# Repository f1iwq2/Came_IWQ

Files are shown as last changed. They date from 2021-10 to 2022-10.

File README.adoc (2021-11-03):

Carte CAME-IWQ
==============

Carte de remplacement pour portail coulissants CAME
ZBX6N/7N - A base d'arduino nano
Documents dans le fichier pdf
Fichiers schéma Kicad
fichiers gerber dans le répertoire trace

Replacement control board for CAME sliding gates
Documents in pdf files
Kicad board schematics files
gerber files in trace directory

https://youtu.be/OYu1DCdmt-g

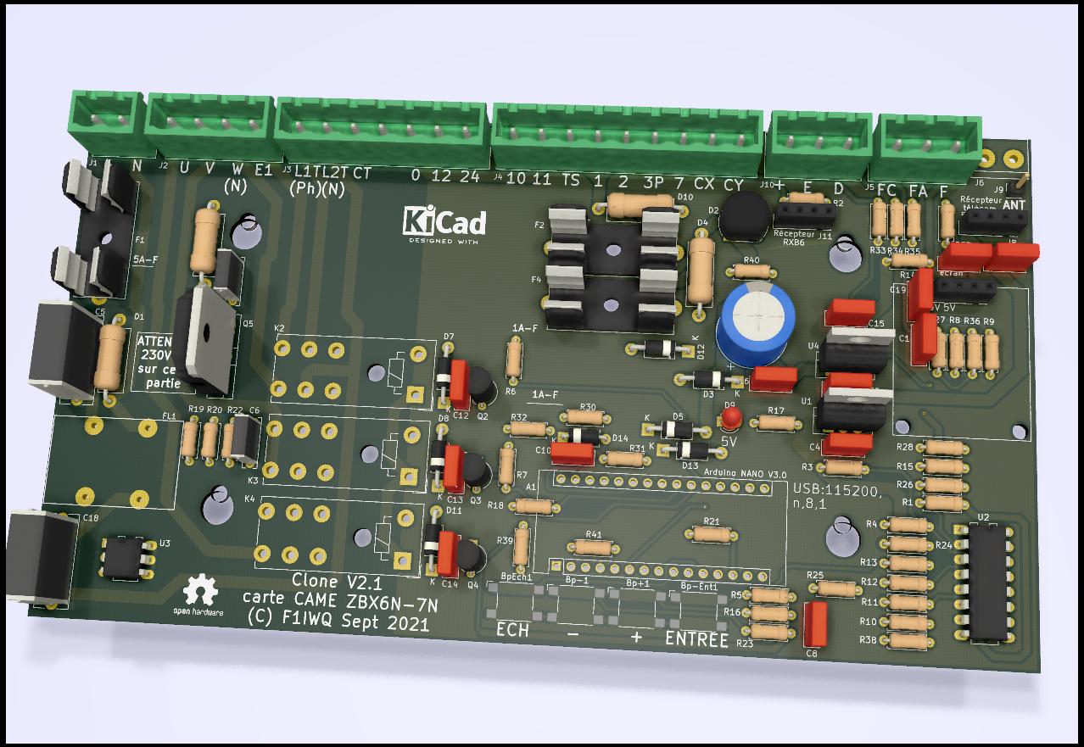
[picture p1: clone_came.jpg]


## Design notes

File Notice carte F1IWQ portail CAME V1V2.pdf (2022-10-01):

## Notice carte F1IWQ clone CAME V1.0/2.0

## En remplacement de la carte ZBX6N/7N

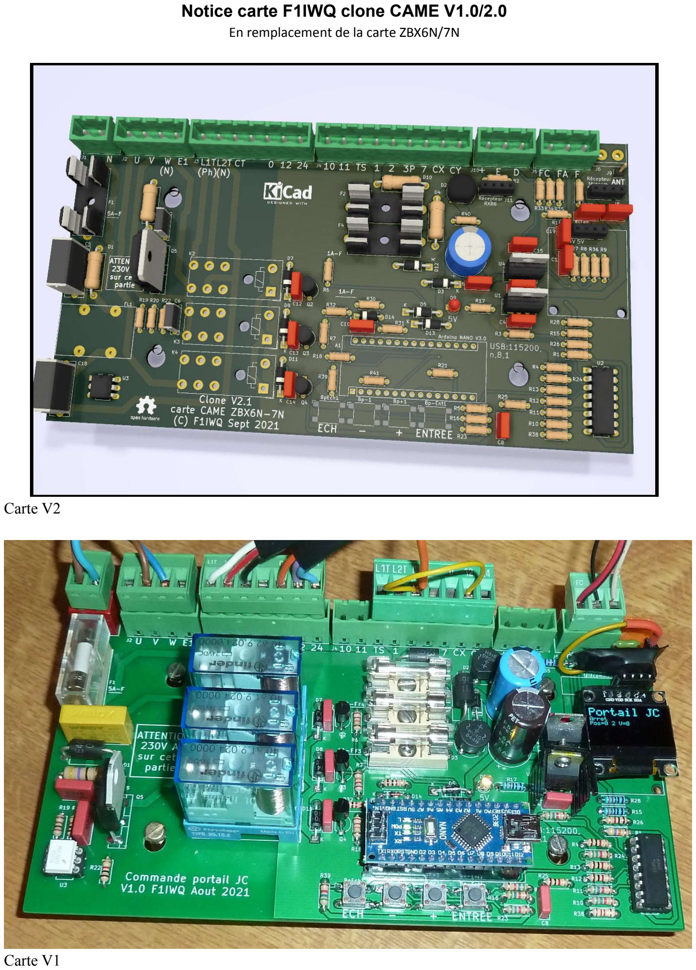
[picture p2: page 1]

## Carte V2

## Carte V1

# Description

## La carte existe en deux versions :

La carte V1.0 dispose d'un connecteur pour un récepteur radio à 1 bornier.
La carte V2.1 dispose de deux connecteurs pour un récepteur à 1 ou 2 bornier(s) (type RXB6).

La carte comporte des protections contre les surtensions par des diodes transil, beaucoup plus réactives que les traditionnelles varistances. En cas de surtension, le fusible associé à la diode brule.

# Montage

Pour la carte V1, souder un strap entre H11 et H12.
Monter les supports de relais avec une vis + écrou M3, de même que les supports des fusibles. Ne pas trop serrer les écrous des supports de relais sous peine de déformation.
Ponter JP1 ou JP2 à la soudure suivant le récepteur de télécommande utilisé (carte V1.0) pour les récepteurs signalés plus bas, souder JP2.
Insérer l'écran OLED sur le connecteur J7 et mettre deux vis / écrous M2,5 avec entretoise.
Insérer le récepteur de télécommande.
Insérer les fusibles rapides 5x20 sur leurs supports. Leur valeur est sérigraphiée. F1=5A-F, F2 F3 F4=1A-F. Insérer l'arduino NANO programmé à l'emplacement A1, prise USB vers la droite.
Monter la carte dans le boitier CAME et insérer les borniers. Il est impératif de respecter la phase (L) et le neutre (N) sur le bornier J1.

L'origine de la mesure par l'encodeur est fixée sur le fin de course arrière (portail ouvert). Tant que cette position n'a pas été reconnue (c’est-à-dire que le fdc arrière doit avoir été actionné par le portail au moins une fois), le portail se déplacera en petite vitesse (PV).

# Télécommande

Le récepteur utilise la librairie rc-switch, compatible uniquement avec les télécommandes à code fixe équipées

## des puces suivantes :

## SC5262 / SC5272 Séries 2262: HX2262 / LX2262 / PT2262 Séries 2272: HX2272 / PT2272 / Séries 1527: EV1527 / RT1527 / FP1527 / HS1527 Intertechno outlets HT6P20X

La télécommande TOP 432 EV CAME fonctionne quelque fois. Les télécommandes Somfy, Cardin ne fonctionnent pas.

Rc-switch permet de décoder 12 protocoles. Le tableau ci-dessous donne le nom du protocole en fonction du numéro du protocole affiché.

1 | EV1527
2
3
4
5
6 | HTP20B
7 | HS2303-PT (utilisé dans la télécommande AUKEY)
8 | Conrad RS-200 RX
9 | Conrad RS-200 TX
10 | 1ByOne Doorbell
11 | HT12E
12 | SM5212

# Circuit imprimé V1.0 avec référencement des composants

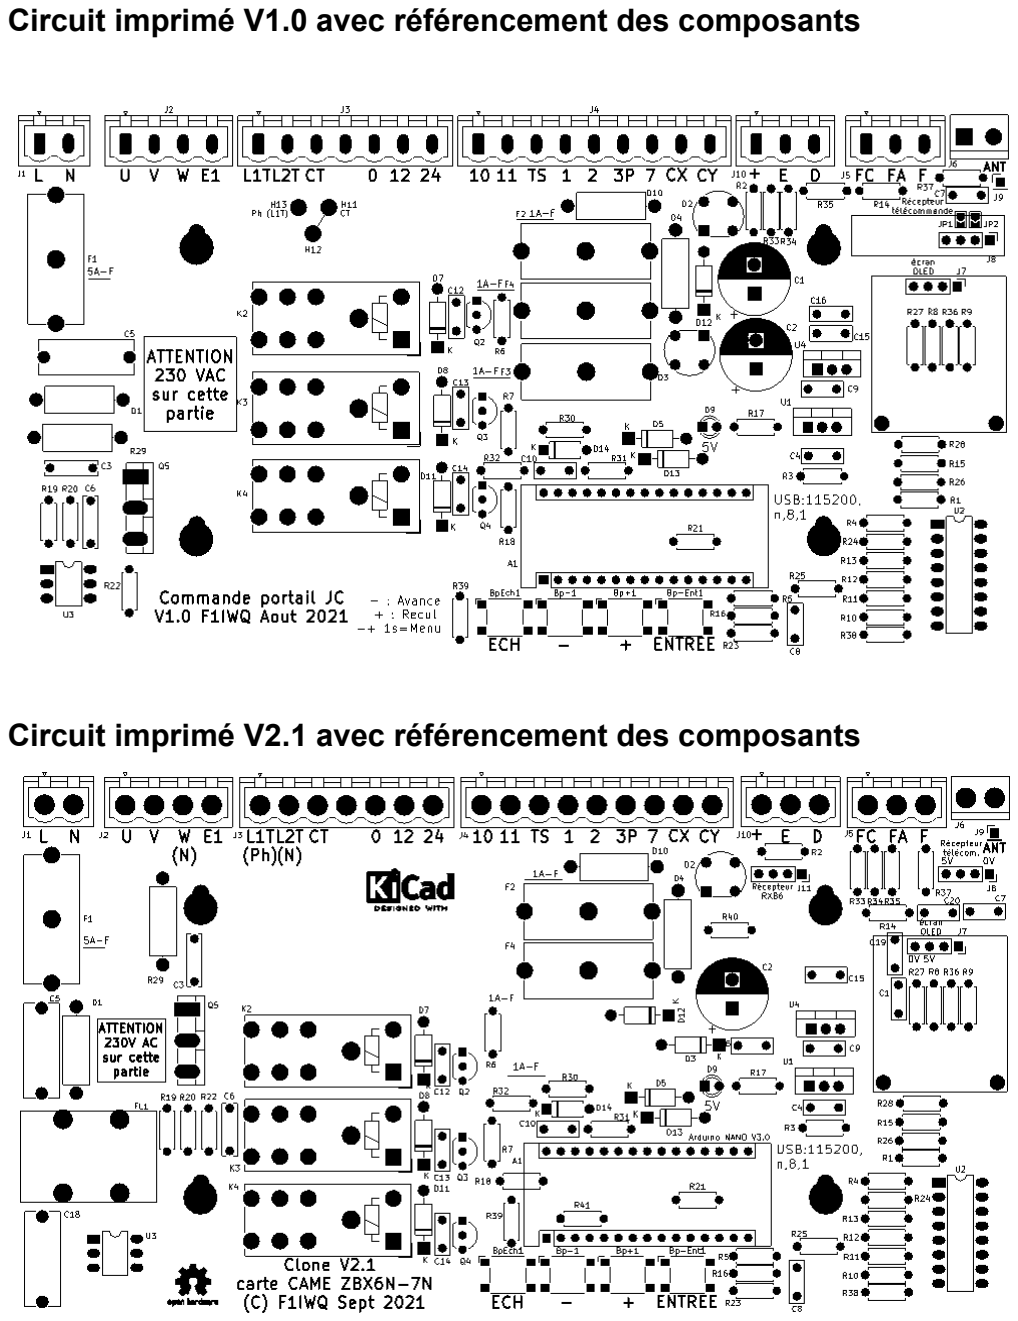
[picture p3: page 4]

# Circuit imprimé V2.1 avec référencement des composants

# Nomenclature V1.0

A1 | Arduino_Nano_v3.x | Module:Arduino_Nano
Bp+1 | SW_MEC_5E | Button_Switch_SMD:SW_SPST_Omron_B3FS-101xP
Bp-1 | SW_MEC_5E | Button_Switch_SMD:SW_SPST_Omron_B3FS-101xP
BpEch1 | SW_MEC_5E | Button_Switch_SMD:SW_SPST_Omron_B3FS-101xP
Bp-Ent1 | SW_MEC_5E | Button_Switch_SMD:SW_SPST_Omron_B3FS-101xP
C1 | 470µF | Capacitor_THT:CP_Radial_D12.5mm_P5.00mm
C10 | 1nF | Capacitor_THT:C_Rect_L7.2mm_W2.5mm_P5.00mm_FKS2_FKP2_MKS2_MKP2
C12 | 100 nF | Capacitor_THT:C_Rect_L7.2mm_W2.5mm_P5.00mm_FKS2_FKP2_MKS2_MKP2
C13 | 100 nF | Capacitor_THT:C_Rect_L7.2mm_W2.5mm_P5.00mm_FKS2_FKP2_MKS2_MKP2
C14 | 100 nF | Capacitor_THT:C_Rect_L7.2mm_W2.5mm_P5.00mm_FKS2_FKP2_MKS2_MKP2
C15 | 100nF | Capacitor_THT:C_Rect_L7.2mm_W2.5mm_P5.00mm_FKS2_FKP2_MKS2_MKP2
C16 | 100nF | Capacitor_THT:C_Rect_L7.2mm_W2.5mm_P5.00mm_FKS2_FKP2_MKS2_MKP2
C2 | 470µF | Capacitor_THT:CP_Radial_D12.5mm_P5.00mm
C3 | 10nF 400V | Capacitor_THT:C_Rect_L9.0mm_W2.5mm_P7.50mm_MKT
C4 | 100nF | Capacitor_THT:C_Rect_L7.2mm_W2.5mm_P5.00mm_FKS2_FKP2_MKS2_MKP2
C5 | 100nF | Capacitor_THT:C_Rect_L16.5mm_W6.0mm_P15.00mm_MKT
C6 | 10nF 400V | Capacitor_THT:C_Rect_L9.0mm_W2.5mm_P7.50mm_MKT
C7 | 100nF | Capacitor_THT:C_Rect_L7.2mm_W2.5mm_P5.00mm_FKS2_FKP2_MKS2_MKP2
C8 | 100nF | Capacitor_THT:C_Rect_L7.2mm_W2.5mm_P5.00mm_FKS2_FKP2_MKS2_MKP2
C9 | 100nF | Capacitor_THT:C_Rect_L7.2mm_W2.5mm_P5.00mm_FKS2_FKP2_MKS2_MKP2
D1 | 1.5KE300CA | Diode_THT:R_Axial_DIN0414_L11.9mm_D4.5mm_P15.24mm_Horizontal
D10 | 1.5KE30CA | Diode_THT:R_Axial_DIN0414_L11.9mm_D4.5mm_P15.24mm_Horizontal
D11 | 1N4004 | Diode_THT:D_DO-41_SOD81_P10.16mm_Horizontal
D12 | 1N4004 | Diode_THT:D_DO-41_SOD81_P10.16mm_Horizontal
D13 | 1N4004 | Diode_THT:D_DO-41_SOD81_P10.16mm_Horizontal
D14 | 5.1V | Diode_THT:D_A-405_P7.62mm_Horizontal
D2 | W04G | Diode_THT:Diode_Bridge_Round_D8.9mm
D3 | W04G | Diode_THT:Diode_Bridge_Round_D8.9mm
D4 | 1.5KE30CA | Diode_THT:R_Axial_DIN0414_L11.9mm_D4.5mm_P15.24mm_Horizontal
D5 | 1N4004 | Diode_THT:D_DO-41_SOD81_P10.16mm_Horizontal
D7 | 1N4004 | Diode_THT:D_DO-41_SOD81_P10.16mm_Horizontal
D8 | 1N4004 | Diode_THT:D_DO-41_SOD81_P10.16mm_Horizontal
D9 | LED | LED_THT:LED_D3.0mm
F1 | Fuse | Fuse:Fuseholder_Cylinder-5x20mm_Schurter_0031_8201_Horizontal_Open + capot
F2 | Fuse | Fuse:Fuseholder_Cylinder-5x20mm_Schurter_0031_8201_Horizontal_Open
F3 | Fuse | Fuse:Fuseholder_Cylinder-5x20mm_Schurter_0031_8201_Horizontal_Open
F4 | Fuse | Fuse:Fuseholder_Cylinder-5x20mm_Schurter_0031_8201_Horizontal_Open
J1 | Conn_01x02_Male | Connector_Phoenix_MSTB:PhoenixContact_MSTBVA_2,5_2-G-5,08_1x02_P5.08mm_Vertical
J10 | Conn_01x03_Male | Connector_Phoenix_MSTB:PhoenixContact_MSTBVA_2,5_3-G-5,08_1x03_P5.08mm_Vertical
J2 | Conn_01x04_Male | Connector_Phoenix_MSTB:PhoenixContact_MSTBVA_2,5_4-G_1x04_P5.08mm_Vertical
J3 | Conn_01x07_Male | Connector_Phoenix_MSTB:PhoenixContact_MSTBVA_2,5_7-G_1x07_P5.08mm_Vertical
J4 | Conn_01x09_Male | Connector_Phoenix_MSTB:PhoenixContact_MSTBVA_2,5_9-G_1x09_P5.08mm_Vertical
J5 | Conn_01x03_Male | Connector_Phoenix_MSTB:PhoenixContact_MSTBVA_2,5_3-G-5,08_1x03_P5.08mm_Vertical
J6 | Screw_Terminal_01x02 | TerminalBlock:TerminalBlock_bornier-2_P5.08mm
J7 | Conn_01x04 | Connector_PinHeader_2.54mm:PinHeader_1x04_P2.54mm_Vertical
J8 | Conn_01x04 | Connector_PinHeader_2.54mm:PinHeader_1x04_P2.54mm_Vertical
J9 | Conn_01x04 | Connector_PinHeader_2.54mm:PinHeader_1x01_P2.54mm_Vertical
JP1 | SolderJumper_2_Open | Jumper:SolderJumper-2_P1.3mm_Open_TrianglePad1.0x1.5mm
JP2 | SolderJumper_2_Open | Jumper:SolderJumper-2_P1.3mm_Open_TrianglePad1.0x1.5mm
K2 | Finder 40.62.9.024V | Relay_THT:Relay_socket_95.15.2
K3 | Finder 40.61.9.024V | Relay_THT:Relay_socket_95.15.2
K4 | Finder 40.61.9.024V | Relay_THT:Relay_socket_95.15.2
Q2 | BS170 | Package_TO_SOT_THT:TO-92L_Inline_Wide
Q3 | BS170 | Package_TO_SOT_THT:TO-92L_Inline_Wide
Q4 | BS170 | Package_TO_SOT_THT:TO-92L_Inline_Wide
Q5 | BTA26-600-BWRG ou BTA26-800-BWRG | Package_TO_SOT_THT:TO-3P-3_Vertical
R1 | 47k | Resistor_THT:R_Axial_DIN0207_L6.3mm_D2.5mm_P7.62mm_Horizontal
R10 | 5,6k | Resistor_THT:R_Axial_DIN0207_L6.3mm_D2.5mm_P7.62mm_Horizontal
R11 | 5,6k | Resistor_THT:R_Axial_DIN0207_L6.3mm_D2.5mm_P7.62mm_Horizontal
R12 | 1k | Resistor_THT:R_Axial_DIN0207_L6.3mm_D2.5mm_P7.62mm_Horizontal
R13 | 1k | Resistor_THT:R_Axial_DIN0207_L6.3mm_D2.5mm_P7.62mm_Horizontal
R14 | 2,7k | Resistor_THT:R_Axial_DIN0207_L6.3mm_D2.5mm_P7.62mm_Horizontal
R15 | 330 | Resistor_THT:R_Axial_DIN0207_L6.3mm_D2.5mm_P7.62mm_Horizontal
R16 | 5,6k | Resistor_THT:R_Axial_DIN0207_L6.3mm_D2.5mm_P7.62mm_Horizontal
R17 | 330 | Resistor_THT:R_Axial_DIN0207_L6.3mm_D2.5mm_P7.62mm_Horizontal
R18 | 12k | Resistor_THT:R_Axial_DIN0207_L6.3mm_D2.5mm_P7.62mm_Horizontal
R19 | 100 | Resistor_THT:R_Axial_DIN0207_L6.3mm_D2.5mm_P7.62mm_Horizontal
R2 | 1,8k | Resistor_THT:R_Axial_DIN0207_L6.3mm_D2.5mm_P7.62mm_Horizontal
R20 | 1k | Resistor_THT:R_Axial_DIN0207_L6.3mm_D2.5mm_P7.62mm_Horizontal
R21 | 330 | Resistor_THT:R_Axial_DIN0207_L6.3mm_D2.5mm_P7.62mm_Horizontal
R22 | 1k | Resistor_THT:R_Axial_DIN0207_L6.3mm_D2.5mm_P7.62mm_Horizontal
R23 | 5,6k | Resistor_THT:R_Axial_DIN0207_L6.3mm_D2.5mm_P7.62mm_Horizontal
R24 | 5,6k | Resistor_THT:R_Axial_DIN0207_L6.3mm_D2.5mm_P7.62mm_Horizontal
R25 | 1k | Resistor_THT:R_Axial_DIN0207_L6.3mm_D2.5mm_P7.62mm_Horizontal
R26 | 1k | Resistor_THT:R_Axial_DIN0207_L6.3mm_D2.5mm_P7.62mm_Horizontal

R27 | 1,8k | Resistor_THT:R_Axial_DIN0207_L6.3mm_D2.5mm_P7.62mm_Horizontal
R28 | 330 | Resistor_THT:R_Axial_DIN0207_L6.3mm_D2.5mm_P7.62mm_Horizontal
R29 | 47 2W | Resistor_THT:R_Axial_DIN0414_L11.9mm_D4.5mm_P15.24mm_Horizontal
R3 | 5,6k | Resistor_THT:R_Axial_DIN0207_L6.3mm_D2.5mm_P7.62mm_Horizontal
R30 | 1k | Resistor_THT:R_Axial_DIN0207_L6.3mm_D2.5mm_P7.62mm_Horizontal
R31 | 5,6k | Resistor_THT:R_Axial_DIN0207_L6.3mm_D2.5mm_P7.62mm_Horizontal
R32 | 1k | Resistor_THT:R_Axial_DIN0207_L6.3mm_D2.5mm_P7.62mm_Horizontal
R33 | 150 | Resistor_THT:R_Axial_DIN0207_L6.3mm_D2.5mm_P7.62mm_Horizontal
R34 | 1k | Resistor_THT:R_Axial_DIN0207_L6.3mm_D2.5mm_P7.62mm_Horizontal
R35 | 10k | Resistor_THT:R_Axial_DIN0207_L6.3mm_D2.5mm_P7.62mm_Horizontal
R36 | 47k | Resistor_THT:R_Axial_DIN0207_L6.3mm_D2.5mm_P7.62mm_Horizontal
R37 | 0 | Resistor_THT:R_Axial_DIN0207_L6.3mm_D2.5mm_P7.62mm_Horizontal
R38 | 1,2k | Resistor_THT:R_Axial_DIN0207_L6.3mm_D2.5mm_P7.62mm_Horizontal
R39 | 5,6k | Resistor_THT:R_Axial_DIN0207_L6.3mm_D2.5mm_P7.62mm_Horizontal
R4 | 1k | Resistor_THT:R_Axial_DIN0207_L6.3mm_D2.5mm_P7.62mm_Horizontal
R5 | 5,6k | Resistor_THT:R_Axial_DIN0207_L6.3mm_D2.5mm_P7.62mm_Horizontal
R6 | 12k | Resistor_THT:R_Axial_DIN0207_L6.3mm_D2.5mm_P7.62mm_Horizontal
R7 | 12k | Resistor_THT:R_Axial_DIN0207_L6.3mm_D2.5mm_P7.62mm_Horizontal
R8 | 2,7k | Resistor_THT:R_Axial_DIN0207_L6.3mm_D2.5mm_P7.62mm_Horizontal
R9 | 2,7k | Resistor_THT:R_Axial_DIN0207_L6.3mm_D2.5mm_P7.62mm_Horizontal
U1 | 7805+radiateur | Package_TO_SOT_THT:TO-220-3_Vertical
U2 | ACPL-844 ou 4xSFH620 | Package_DIP:DIP-16_W7.62mm_LongPads
U3 | MOC3020M | Package_DIP:DIP-6_W7.62mm_LongPads
U4 | 7824+radiateur | Package_TO_SOT_THT:TO-220-3_Vertical

# Nomenclature V2.0

A1 | Arduino_Nano_v3.x | Module:Arduino_Nano
Bp+1 | SW_MEC_5E | Button_Switch_SMD:SW_SPST_Omron_B3FS-101xP
Bp-1 | SW_MEC_5E | Button_Switch_SMD:SW_SPST_Omron_B3FS-101xP
BpEch1 | SW_MEC_5E | Button_Switch_SMD:SW_SPST_Omron_B3FS-101xP
Bp-Ent1 | SW_MEC_5E | Button_Switch_SMD:SW_SPST_Omron_B3FS-101xP
C1 | 100nF | Capacitor_THT:C_Rect_L7.2mm_W2.5mm_P5.00mm_FKS2_FKP2_MKS2_MKP2
C10 | 1nF | Capacitor_THT:C_Rect_L7.2mm_W2.5mm_P5.00mm_FKS2_FKP2_MKS2_MKP2
C12 | 100 nF | Capacitor_THT:C_Rect_L7.2mm_W2.5mm_P5.00mm_FKS2_FKP2_MKS2_MKP2
C13 | 100 nF | Capacitor_THT:C_Rect_L7.2mm_W2.5mm_P5.00mm_FKS2_FKP2_MKS2_MKP2
C14 | 100 nF | Capacitor_THT:C_Rect_L7.2mm_W2.5mm_P5.00mm_FKS2_FKP2_MKS2_MKP2
C15 | 100nF | Capacitor_THT:C_Rect_L7.2mm_W2.5mm_P5.00mm_FKS2_FKP2_MKS2_MKP2
C16 | 100nF | Capacitor_THT:C_Rect_L7.2mm_W2.5mm_P5.00mm_FKS2_FKP2_MKS2_MKP2
C18 | 100nF 400V | Capacitor_THT:C_Rect_L16.5mm_W6.0mm_P15.00mm_MKT
C19 | 100nF | Capacitor_THT:C_Rect_L7.2mm_W2.5mm_P5.00mm_FKS2_FKP2_MKS2_MKP2
C2 | 1000µF 35V | Capacitor_THT:CP_Radial_D12.5mm_P5.00mm
C20 | 100nF | Capacitor_THT:C_Rect_L7.2mm_W2.5mm_P5.00mm_FKS2_FKP2_MKS2_MKP2
C3 | 10nF 400V | Capacitor_THT:C_Rect_L9.0mm_W2.5mm_P7.50mm_MKT
C4 | 100nF | Capacitor_THT:C_Rect_L7.2mm_W2.5mm_P5.00mm_FKS2_FKP2_MKS2_MKP2
C5 | 100nF 400V | Capacitor_THT:C_Rect_L16.5mm_W6.0mm_P15.00mm_MKT
C6 | 10nF 400V | Capacitor_THT:C_Rect_L9.0mm_W2.5mm_P7.50mm_MKT
C7 | 100nF | Capacitor_THT:C_Rect_L7.2mm_W2.5mm_P5.00mm_FKS2_FKP2_MKS2_MKP2
C8 | 100nF | Capacitor_THT:C_Rect_L7.2mm_W2.5mm_P5.00mm_FKS2_FKP2_MKS2_MKP2
C9 | 100nF | Capacitor_THT:C_Rect_L7.2mm_W2.5mm_P5.00mm_FKS2_FKP2_MKS2_MKP2
D1 | 1.5KE400CA | Diode_THT:R_Axial_DIN0414_L11.9mm_D4.5mm_P15.24mm_Horizontal
D10 | 1.5KE39CA | Diode_THT:R_Axial_DIN0414_L11.9mm_D4.5mm_P15.24mm_Horizontal
D11 | 1N4004 | Diode_THT:D_DO-41_SOD81_P10.16mm_Horizontal
D12 | 1N4004 | Diode_THT:D_DO-41_SOD81_P10.16mm_Horizontal
D13 | 1N4004 | Diode_THT:D_DO-41_SOD81_P10.16mm_Horizontal
D14 | DZ5.1V | Diode_THT:D_A-405_P7.62mm_Horizontal
D2 | W04G | Diode_THT:Diode_Bridge_Round_D8.9mm
D3 | 1N4004 | Diode_THT:D_DO-41_SOD81_P10.16mm_Horizontal
D4 | 1.5KE39CA | Diode_THT:R_Axial_DIN0414_L11.9mm_D4.5mm_P15.24mm_Horizontal
D5 | 1N4004 | Diode_THT:D_DO-41_SOD81_P10.16mm_Horizontal
D7 | 1N4004 | Diode_THT:D_DO-41_SOD81_P10.16mm_Horizontal
D8 | 1N4004 | Diode_THT:D_DO-41_SOD81_P10.16mm_Horizontal
D9 | LED | LED_THT:LED_D3.0mm
F1 | Fuse | Fuse:Fuseholder_Cylinder-5x20mm_Schurter_0031_8201_Horizontal_Open + capot
F2 | Fuse | Fuse:Fuseholder_Cylinder-5x20mm_Schurter_0031_8201_Horizontal_Open
F4 | Fuse | Fuse:Fuseholder_Cylinder-5x20mm_Schurter_0031_8201_Horizontal_Open
FL1 | Wurth 7446223001 | Filter:Filtre_wurth
J1 | Conn_01x02_Male | Connector_Phoenix_MSTB:PhoenixContact_MSTBVA_2,5_2-G-5,08_1x02_P5.08mm_Vertical
J10 | Conn_01x03_Male | Connector_Phoenix_MSTB:PhoenixContact_MSTBVA_2,5_3-G-5,08_1x03_P5.08mm_Vertical
J11 | Conn_01x04 | Connector_PinSocket_2.54mm:PinSocket_1x04_P2.54mm_Vertical
J2 | Conn_01x04_Male | Connector_Phoenix_MSTB:PhoenixContact_MSTBVA_2,5_4-G-5,08_1x04_P5.08mm_Vertical
J3 | Conn_01x07_Male | Connector_Phoenix_MSTB:PhoenixContact_MSTBVA_2,5_7-G-5,08_1x07_P5.08mm_Vertical
J4 | Conn_01x09_Male | Connector_Phoenix_MSTB:PhoenixContact_MSTBVA_2,5_9-G-5,08_1x09_P5.08mm_Vertical
J5 | Conn_01x03_Male | Connector_Phoenix_MSTB:PhoenixContact_MSTBVA_2,5_3-G-5,08_1x03_P5.08mm_Vertical
J6 | Screw_Terminal_01x02 | TerminalBlock:TerminalBlock_bornier-2_P5.08mm
J7 | Conn_01x04 | Connector_PinSocket_2.54mm:PinSocket_1x04_P2.54mm_Vertical
J8 | Conn_01x04 | Connector_PinSocket_2.54mm:PinSocket_1x04_P2.54mm_Vertical
J9 | Conn_01x04 | Connector_PinHeader_2.54mm:PinHeader_1x01_P2.54mm_Vertical
K2 | Finder 40.62.9.024V | Relay_THT:Relay_socket_95.15.2
K3 | Finder 40.61.9.024V | Relay_THT:Relay_socket_95.15.2
K4 | Finder 40.61.9.024V | Relay_THT:Relay_socket_95.15.2
Q2 | BS170 | Package_TO_SOT_THT:TO-92L_Inline_Wide
Q3 | BS170 | Package_TO_SOT_THT:TO-92L_Inline_Wide
Q4 | BS170 | Package_TO_SOT_THT:TO-92L_Inline_Wide
Q5 | BTA26-600-BWRG | Package_TO_SOT_THT:TO-3P-3_Vertical
R1 | 47k | Resistor_THT:R_Axial_DIN0207_L6.3mm_D2.5mm_P7.62mm_Horizontal
R10 | 5,6k | Resistor_THT:R_Axial_DIN0207_L6.3mm_D2.5mm_P7.62mm_Horizontal
R11 | 5,6k | Resistor_THT:R_Axial_DIN0207_L6.3mm_D2.5mm_P7.62mm_Horizontal
R12 | 1k | Resistor_THT:R_Axial_DIN0207_L6.3mm_D2.5mm_P7.62mm_Horizontal
R13 | 1k | Resistor_THT:R_Axial_DIN0207_L6.3mm_D2.5mm_P7.62mm_Horizontal
R14 | 2,7k | Resistor_THT:R_Axial_DIN0207_L6.3mm_D2.5mm_P7.62mm_Horizontal
R15 | 330 | Resistor_THT:R_Axial_DIN0207_L6.3mm_D2.5mm_P7.62mm_Horizontal
R16 | 5,6k | Resistor_THT:R_Axial_DIN0207_L6.3mm_D2.5mm_P7.62mm_Horizontal
R17 | 330 | Resistor_THT:R_Axial_DIN0207_L6.3mm_D2.5mm_P7.62mm_Horizontal
R18 | 12k | Resistor_THT:R_Axial_DIN0207_L6.3mm_D2.5mm_P7.62mm_Horizontal
R19 | 100 | Resistor_THT:R_Axial_DIN0207_L6.3mm_D2.5mm_P7.62mm_Horizontal
R2 | 4,7k | Resistor_THT:R_Axial_DIN0207_L6.3mm_D2.5mm_P7.62mm_Horizontal
R20 | 1k | Resistor_THT:R_Axial_DIN0207_L6.3mm_D2.5mm_P7.62mm_Horizontal
R21 | 330 | Resistor_THT:R_Axial_DIN0207_L6.3mm_D2.5mm_P7.62mm_Horizontal
R22 | 1k | Resistor_THT:R_Axial_DIN0207_L6.3mm_D2.5mm_P7.62mm_Horizontal
R23 | 5,6k | Resistor_THT:R_Axial_DIN0207_L6.3mm_D2.5mm_P7.62mm_Horizontal
R24 | 5,6k | Resistor_THT:R_Axial_DIN0207_L6.3mm_D2.5mm_P7.62mm_Horizontal
R25 | 1k | Resistor_THT:R_Axial_DIN0207_L6.3mm_D2.5mm_P7.62mm_Horizontal
R26 | 1k | Resistor_THT:R_Axial_DIN0207_L6.3mm_D2.5mm_P7.62mm_Horizontal

R27 | 4,7k | Resistor_THT:R_Axial_DIN0207_L6.3mm_D2.5mm_P7.62mm_Horizontal
R28 | 330 | Resistor_THT:R_Axial_DIN0207_L6.3mm_D2.5mm_P7.62mm_Horizontal
R29 | 47 2W | Resistor_THT:R_Axial_DIN0414_L11.9mm_D4.5mm_P15.24mm_Horizontal
R3 | 5,6k | Resistor_THT:R_Axial_DIN0207_L6.3mm_D2.5mm_P7.62mm_Horizontal
R30 | 1k | Resistor_THT:R_Axial_DIN0207_L6.3mm_D2.5mm_P7.62mm_Horizontal
R31 | 6,8k | Resistor_THT:R_Axial_DIN0207_L6.3mm_D2.5mm_P7.62mm_Horizontal
R32 | 1k | Resistor_THT:R_Axial_DIN0207_L6.3mm_D2.5mm_P7.62mm_Horizontal
R33 | 150 | Resistor_THT:R_Axial_DIN0207_L6.3mm_D2.5mm_P7.62mm_Horizontal
R34 | 1k | Resistor_THT:R_Axial_DIN0207_L6.3mm_D2.5mm_P7.62mm_Horizontal
R35 | 10k | Resistor_THT:R_Axial_DIN0207_L6.3mm_D2.5mm_P7.62mm_Horizontal
R36 | 47k | Resistor_THT:R_Axial_DIN0207_L6.3mm_D2.5mm_P7.62mm_Horizontal
R37 | 0 | Resistor_THT:R_Axial_DIN0207_L6.3mm_D2.5mm_P7.62mm_Horizontal
R38 | 1,2k | Resistor_THT:R_Axial_DIN0207_L6.3mm_D2.5mm_P7.62mm_Horizontal
R39 | 5,6k | Resistor_THT:R_Axial_DIN0207_L6.3mm_D2.5mm_P7.62mm_Horizontal
R4 | 1k | Resistor_THT:R_Axial_DIN0207_L6.3mm_D2.5mm_P7.62mm_Horizontal
R40 | 220 | Resistor_THT:R_Axial_DIN0207_L6.3mm_D2.5mm_P7.62mm_Horizontal
R41 | 47k | Resistor_THT:R_Axial_DIN0207_L6.3mm_D2.5mm_P7.62mm_Horizontal
R5 | 5,6k | Resistor_THT:R_Axial_DIN0207_L6.3mm_D2.5mm_P7.62mm_Horizontal
R6 | 12k | Resistor_THT:R_Axial_DIN0207_L6.3mm_D2.5mm_P7.62mm_Horizontal
R7 | 12k | Resistor_THT:R_Axial_DIN0207_L6.3mm_D2.5mm_P7.62mm_Horizontal
R8 | 2,7k | Resistor_THT:R_Axial_DIN0207_L6.3mm_D2.5mm_P7.62mm_Horizontal
R9 | 2,7k | Resistor_THT:R_Axial_DIN0207_L6.3mm_D2.5mm_P7.62mm_Horizontal
U1 | 7805+radiateur | Package_TO_SOT_THT:TO-220-3_Vertical
U2 | ACPL-844 ou 4xSFH620 | Package_DIP:DIP-16_W7.62mm_LongPads
U3 | MOC3020M | Package_DIP:DIP-6_W7.62mm_LongPads
U4 | 7824+radiateur | Package_TO_SOT_THT:TO-220-3_Vertical

## Connecteurs phoenix contact:

Ces connecteurs sont composés d'une partie mâle à souder et d'une partie femelle à bornier constituant deux références de commande séparées.
| | | Commande | Commande
Nb | | | Conn mâle | conn femelle
pts | Rep | Type | à souder | à bornier
2 | J1 | MSTBVA 2,5/2-G-5,08 | 17 55 73 6 | 17 57 01 9
3 | J5-J10 MSTBVA 2,5/3-G-5,08 | 17 55 74 9 | 17 57 02 2
4 | J2 | MSTBVA 2,5/4-G-5,08 | 17 55 75 2 | 17 57 03 5
7 | J3 | MSTBVA 2,5/7-G-5,08 | 17 55 78 1 | 17 57 06 4
9 | J4 | MSTBVA 2,5/9-G-5,08 | 17 55 80 4 | 17 57 08 0

Les régulateurs U1 et U4 doivent absolument être montés sur des radiateurs.

R37 est un fusible 1A au format résistance. Ref Little fuse 251001.NRT1L. A monter sur support.

Les relais K2 K3 et K4 sont montés sur support finder référence 95.15.2. Attention K2 est un relais 2RT ; K3 et K4 sont des relais 1RT.

A1 est un arduino NANO, il peut être un clone chinois.

## Le module OLED est un 0,96" 128x64

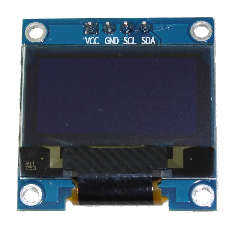
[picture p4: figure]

## Le récepteur radio commande (433,920 MHz) est MX-RM-5V (peu performant)

## ou TDCA RX500A 433,920 MHz (plus sensible)

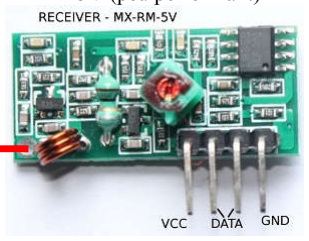
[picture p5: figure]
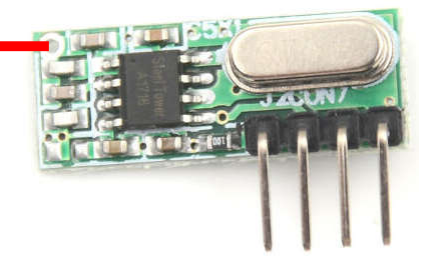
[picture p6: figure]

ou RXB6 (super hétérodyne : plus sensible, plus sélectif) ; nécessite la version 2 de la carte.

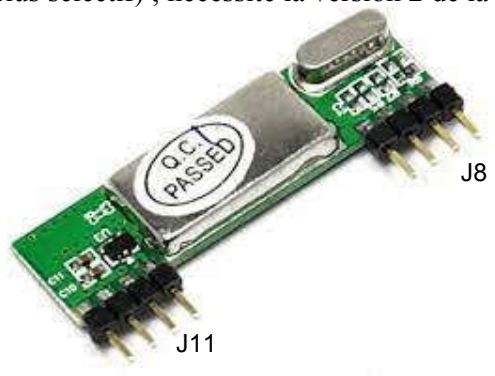
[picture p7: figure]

Le module RXB6 ci-dessus est à enficher sur les connecteurs J8 et J11.

Les modules MX-RM-5V et TDCA RX500A sont à enficher sur le connecteur J8. Pour ces deux récepteurs, il faut souder un fil d'antenne du trait rouge jusqu'au point J9 via un fil.

Il est conseillé d'isoler avec du ruban adhésif électricien l'arrière et le devant des récepteurs.

### antenne

### antenne

# Liste des écrans

## Menu

L'entrée dans le menu pour le paramétrage se fait en appuyant sur le bouton ENTREE pendant 1 seconde.

## Ecran 1

## L'écran menu affiche des paramètres modifiables ou non ainsi que des commandes :

## Apprentissage Sens d'ouverture=x Sequencement=x Sauvegarde EPROM Gestion telecomm Affichage entrees Tps max fonction:xx Tps accel Tps decel

## Ecran 2: gestion des télécommandes

Pour changer de ligne appuyer sur + ou -.

## Pour choisir une ligne appuyer sur ENTREE Pour sortie appuyer sur ECH

## Apprentissage :

Effectue un aller-retour du portail pour fixer l'origine de l'encodeur et les positions de ralentissement avant et arrière dans l'eeprom.
Sens d'ouverture 0 ou 1 : correspond au paramètre F54 0=ouverture à gauche 1=ouverture à droite Sequencement 0 ou 1 : correspond au paramètre F7 0=pas à pas (ouverture fermeture sans arrêt)

## 1=séquentielle (ouverture arret fermeture arret) Sauvegarde EPROM : écrit les paramètres modifiés dans l'EPROM pour la sauvegarde Gestion telecommandes : affiche/ajoute/supprime des télécommandes

### **MENU** >Apprentissage Sens d'ouverture=0 Sequencement=1 Sauvegarde EPROM Gestion telecomm Affichage entrees Tps max fonction:99

1 telecomm.

>Ajouter telecom.
Liste/Suppr telecom.

## Affichage des entrées : affiche les entrées en dynamique (fin de course et boutons)

Tps max fonctionn: Temps maximal de fonctionnement en secondes au-delà duquel le portail s'arrête. Tps accel/decel : Temps de d'accélération et de décélération en dixièmes de secondes.

## Pour ajouter une télécommande

## Sélectionner la ligne Gestion telecommandes Sélectionner "Ajouter telecom" et appuyer sur ENTREE

Appuyer sur le bouton de la télécommande à ajouter.
Si le nombre maximal de télécommandes est atteint, un message d'erreur s'affiche.
Si la télécommande avait déjà été ajoutée, un message s'affiche.
Si rien ne s'affiche quand on appuie sur la télécommande, c'est qu'elle n'est pas reconnue (fréquence ou protocole non reconnus).
Après avoir ajouté une ou plusieurs télécommandes, ne pas oublier d'écrire l'EEPROM pour la sauvegarde.

Liste et suppression des télécommandes : sélectionner "Liste/Suppr des telecom" et appuyer sur ENTREE

Le nombre de télécommandes est affiché (maximum 20).

## La première colonne affiche le numéro de la télécommande

La deuxième colonne affiche le code d'identification de la télécommande (plus précisément d'un de ses

## boutons)

## Pour supprimer une télécommande :

## Sélectionner la télécommande à supprimer Supprimer la télécommande sélectionnée en appuyant 1s sur ENTREE

Après avoir supprimé une ou plusieurs télécommandes, ne pas oublier d'écrire l'EEPROM pour la sauvegarde.

## Mode exploitation

En mode exploitation (hors mode menu) si on appuie sur une télécommande, et que le protocole est reconnu,

## l'écran affiche les informations transmises par la télécommande :

8745 est le code du bouton de la télécommande qui vient d'envoyer le signal.

## 12b signifie que c'est un code de 12 bits

Pr:11 signifie que c'est le protocole 11.

## PORTAIL IWQ

### Pos=5465 15s V=208

### 8745 12b Pr:11 OK

2telecomm.

>1 26898
2 94119

OK que la télécommande est enregistrée en EPROM, et qu'elle est donc reconnue.

La position du portail par l'encodeur est affichée (5465).
Si un mouvement est en cours, le temps en secondes de la durée du mouvement est affiché (ici 15s).

## V=208 indique la vitesse du portail (en points encodeur/0,3s)

Si la durée de mouvement est supérieure au temps maximal de fonctionnement, le mouvement s'arrête sur un message d'erreur.

Si la cellule est occultée (entrée CX sur bornier J4), un message s'affiche et le portail ne pourra pas être manœuvré.

## Un appui sur la touche "+" avance le portail Un appui sur la touche "-" recule le portail Un appui sur la touche "ECH" arrête le portail

En cours d'avancée si un obstacle survient, le portail recule en petite vitesse. En cours de recul, si un obstacle survient, le portail s'arrête.

# Erreurs pouvant être affichées

## - Secteur non trouvé

Indique que la tension secteur n'a pas été trouvée.

## - Erreur mvt trop long

Indique que le temps maximum de fonctionnement a été atteint. Cette erreur arrête le portail.

## - Encodeur muet

L'encodeur n'a pas envoyé de changement de position du moteur alors qu'un mouvement est en cours. Cette erreur arrête le portail si celui-ci est en mouvement de recul, et recule le portail si celui-ci est en mouvement d'avance.

# Consommation du 24VAC

## Consommations relevées sans accessoires branchés sur 10-11 : Au repos : 153 mA En fonctionnement : 263 mA

# Programme Arduino

Le programme est unique pour les deux versions de la carte, il existe une directive de compilation pour la destination du programme en V1 ou V2.

L'entrée analogiques "Onde" est acquise en sous-programme IRQ Timer1. Pour acquérir les valeurs analogiques en temps masqué, le programme manipule directement les registres de l'ATMega328P.

Sur la V1.0 l'encodeur est sur la broche D8, ce qui nécessite de faire réagir l'interruption PCINT0.
Sur la V2.0 l'encodeur est sur la broche D3, ce qui nécessite de faire réagir l'interruption INT1.

Il existe une directive de compilation V1/V2 pour adapter le programme à la version de la carte :

#define V1 // carte V1.0 ou V2.0

Le nombre de boutons de télécommandes maximal est de 20. Il peut être augmenté à concurrence de la saturation mémoire des variables globales.

#define | Nbre_Max_telecom 20 | // nombre maxi de télécommandes

L'interruption timer 1 est générée toutes les 217 µs. Elle gère la génération du signal gâchette du triac U3 vers Q5, pour la modulation de vitesse GV/PV. L'onde secteur est numérisée pour permettre d'avoir le départ du pilotage de la gâchette après changement de signe de l'onde secteur. En GV le triac envoie la totalité de la sinusoïde secteur. En PV, le triac envoie une sinusoïde sur deux (réduction de 50% de la vitesse).

La modulation de vitesse peut être également obtenue de 0 à 100% en faisant varier l'angle de retard à l'amorçage de la gâchette du triac. Dans ce cas on envoie une partie de la sinusoïde à 50 Hz:

La liaison USB dispose d'un terminal de commandes permet de piloter le moteur, de changer des variables etc. Taper ? sur un terminal USB à 115200 bauds pour avoir la liste des commandes disponibles (terminal arduino). Il permet également de piloter le menu grâce aux touches "ENTREE" "8+entrée" pour - et "2+entrée" pour +.

Attention: le programme ne fonctionne pas si l'écran OLED n'est pas alimenté.

### Sinusoïde en sortie du triac en GV (mode1/1)

### Sinusoïde en sortie du triac en PV (mode 1/2)

### Sinusoïde en sortie du triac en décélération de GV à PV (mode 2/3)

## Options internes du programme

## Le programme dispose de deux modes:

Le mode test qui permet de le tester sans encodeur. Positionner Mode_test à HIGH dans la section initialisations.

Le mode temps qui permet de faire fonctionner le portail sans encodeur. L'encodeur ne sert qu'a passer de GV en PV sur la position atteinte. Si l'encodeur est en panne ou inexistant, le mode temps utilise la temporisation de fonctionnement pour passer de GV en PV. Attention, il faut ajuster par programme la valeur temporelle de

## commutation:

// passer en PV
if (
(posOk & (PosEncodeur<PosRalenti_ouv) & !memo_lent & !mode_test & !mode_temps) |

### (mode_temps & (cpt_mvt>15)) ← 15 est à ajuster manuellement

)
aux lignes 622 et 653.

La variable correspondante est mode_temps.

# Prix

La carte revient à environ 70€ selon les fournisseurs.

## Platine seule : 4€ Composants : 65€

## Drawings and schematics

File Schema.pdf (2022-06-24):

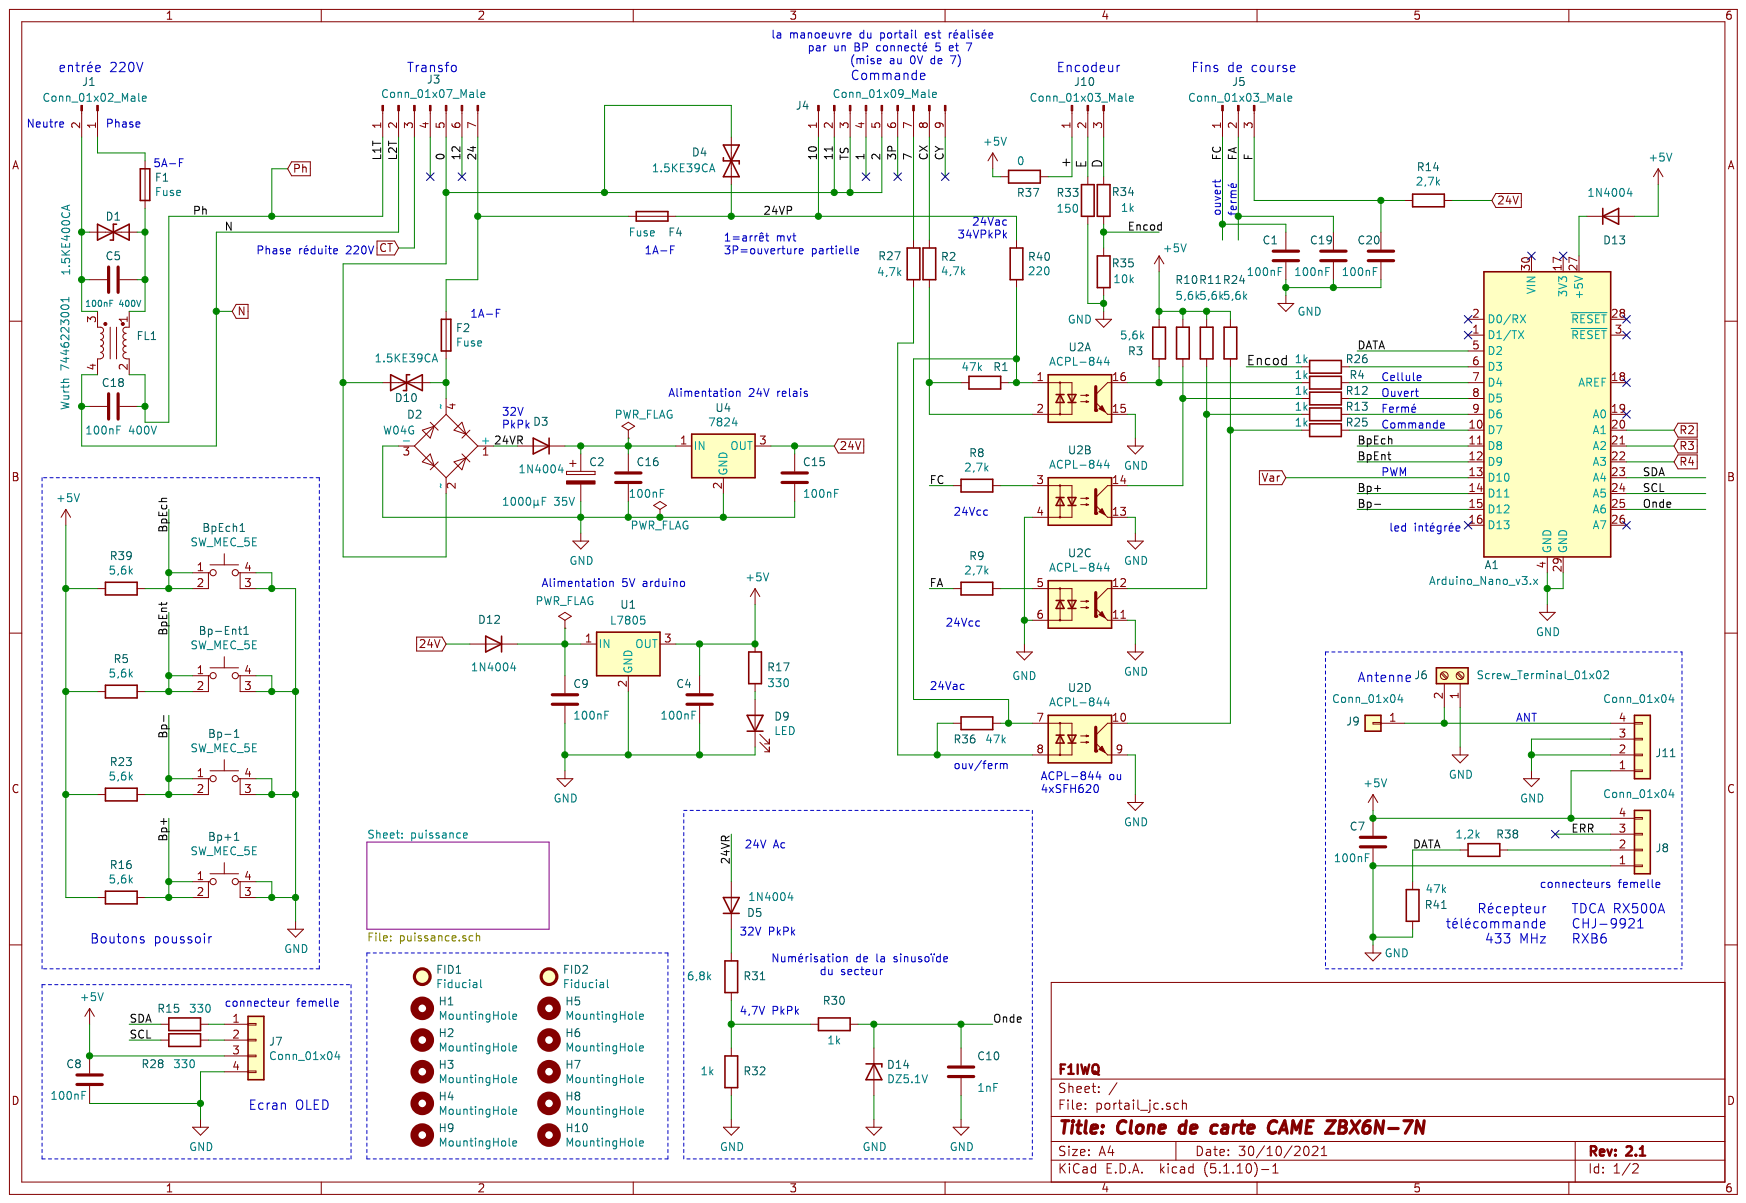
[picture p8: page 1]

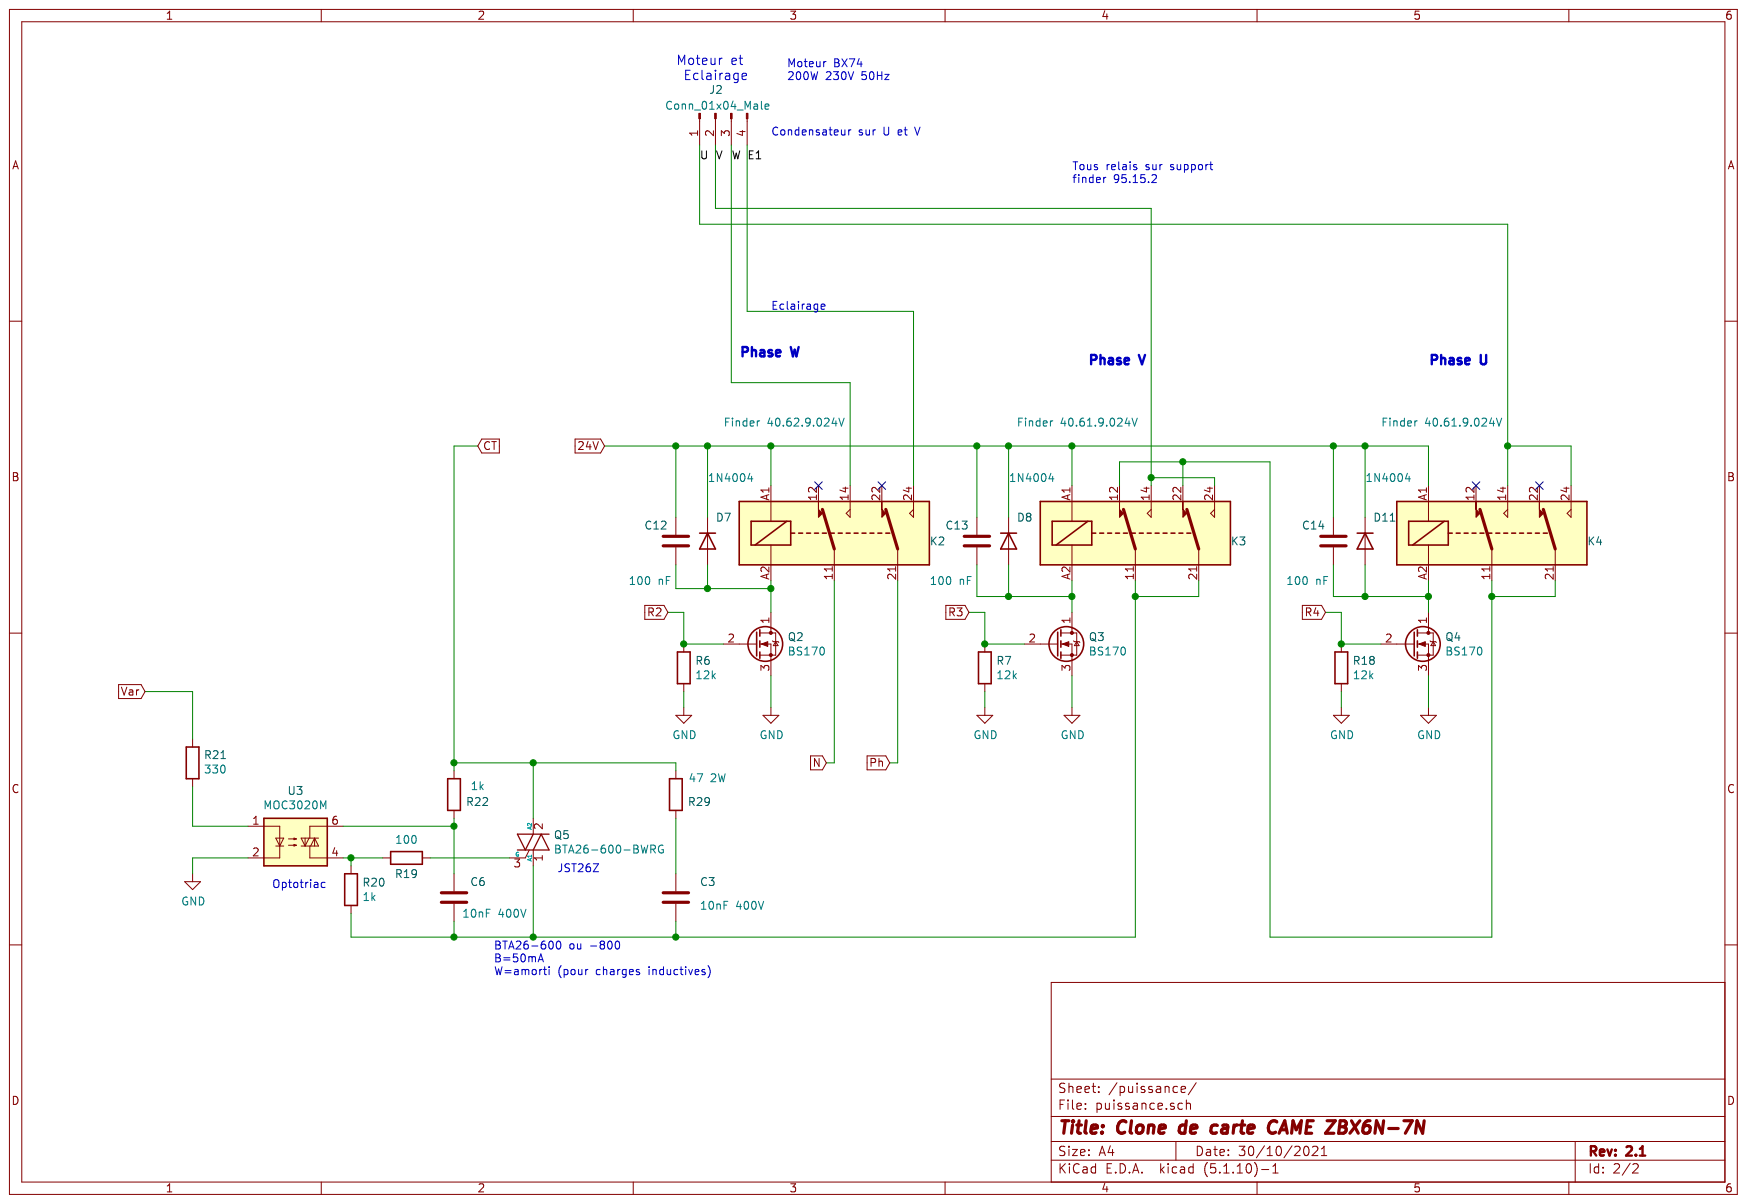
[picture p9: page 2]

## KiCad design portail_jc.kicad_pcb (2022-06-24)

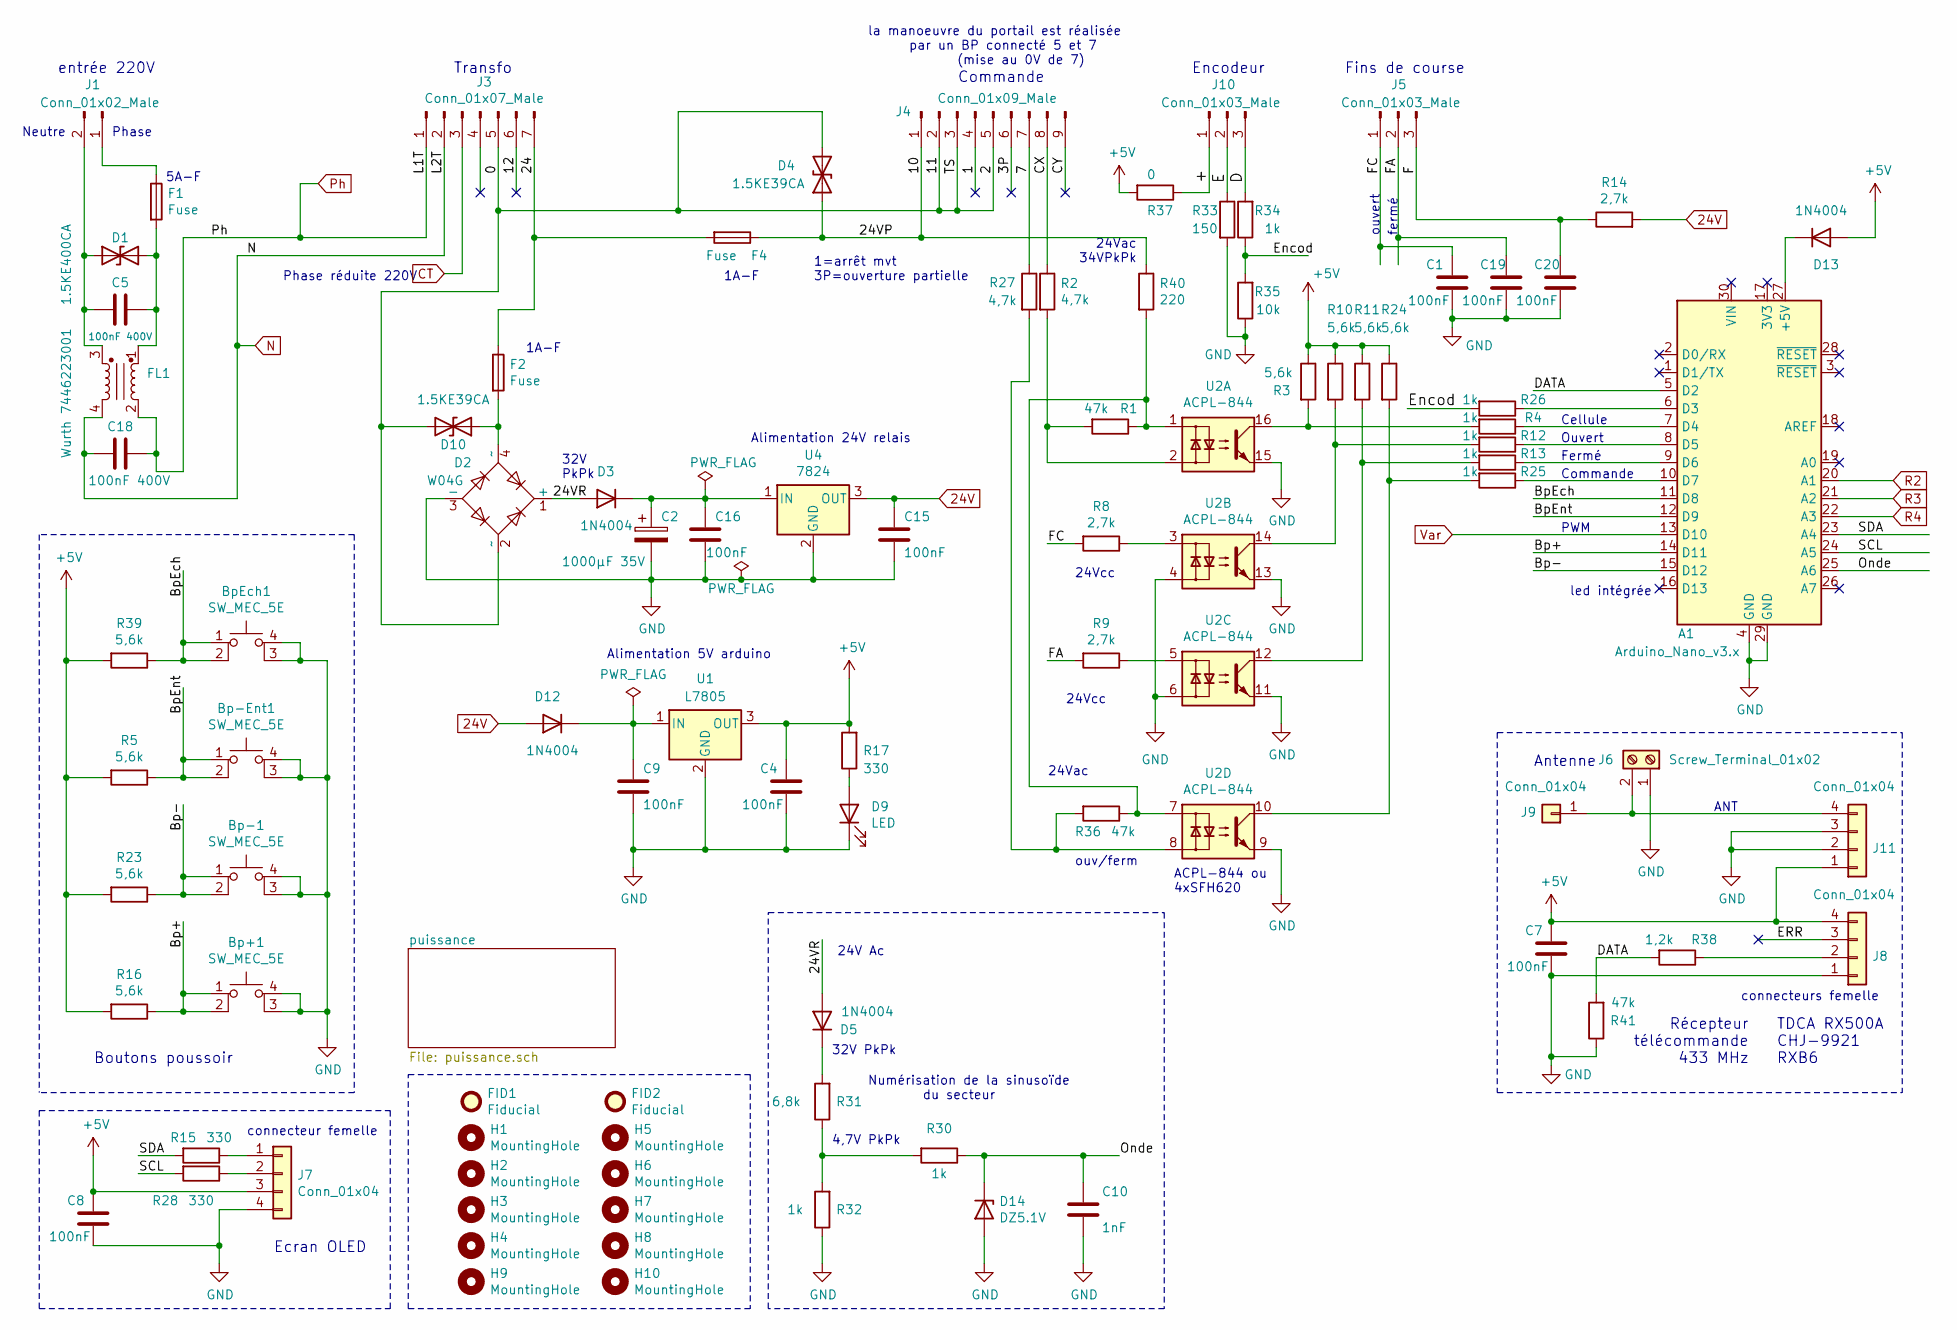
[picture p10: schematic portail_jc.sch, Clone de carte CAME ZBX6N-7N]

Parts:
A1: Arduino_Nano_v3.x; Arduino_Nano
Bp+1: SW_MEC_5E; SW_SPST_Omron_B3FS-101xP
Bp-1: SW_MEC_5E; SW_SPST_Omron_B3FS-101xP
Bp-Ent1: SW_MEC_5E; SW_SPST_Omron_B3FS-101xP
BpEch1: SW_MEC_5E; SW_SPST_Omron_B3FS-101xP
C1, C4, C7, C8, C9, C15, C16, C19, C20: 100nF; C_Rect_L7.2mm_W2.5mm_P5.00mm_FKS2_FKP2_MKS2_MKP2
C2: 1000µF 35V; CP_Radial_D12.5mm_P5.00mm
C5, C18: 100nF 400V; C_Rect_L16.5mm_W6.0mm_P15.00mm_MKT
C10: 1nF; C_Rect_L7.2mm_W2.5mm_P5.00mm_FKS2_FKP2_MKS2_MKP2
D1: 1.5KE400CA; R_Axial_DIN0414_L11.9mm_D4.5mm_P15.24mm_Horizontal
D2: W04G; Diode_Bridge_Round_D8.9mm
D3, D5, D12, D13: 1N4004; D_DO-41_SOD81_P10.16mm_Horizontal
D4, D10: 1.5KE39CA; R_Axial_DIN0414_L11.9mm_D4.5mm_P15.24mm_Horizontal
D9: LED; LED_D3.0mm
D14: DZ5.1V; D_A-405_P7.62mm_Horizontal
F1, F2, F4: Fuse; Fuseholder_Cylinder-5x20mm_Schurter_0031_8201_Horizontal_Op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
FID1: Fiducial; KiCad-Logo2_6mm_SilkScreen
FID2: Fiducial; OSHW-Logo2_9.8x8mm_SilkScreen
FL1: Wurth 7446223001; Filtre_wurth
H1, H2, H3, H4: MountingHole; MountingHole_3.2mm_M3
H5, H6, H7, H8: MountingHole; MountingHole_6.4mm_M6
H9, H10: MountingHole; MountingHole_2.7mm_M2.5
J1: Conn_01x02_Male; PhoenixContact_MSTBVA_2,5_2-G-5,08_1x02_P5.08mm_Vertical
J3: Conn_01x07_Male; PhoenixContact_MSTBVA_2,5_7-G-5,08_1x07_P5.08mm_Vertical
J4: Conn_01x09_Male; PhoenixContact_MSTBVA_2,5_9-G-5,08_1x09_P5.08mm_Vertical
J5, J10: Conn_01x03_Male; PhoenixContact_MSTBVA_2,5_3-G-5,08_1x03_P5.08mm_Vertical
J6: Screw_Terminal_01x02; TerminalBlock_bornier-2_P5.08mm
J7, J8, J11: Conn_01x04; PinSocket_1x04_P2.54mm_Vertical
J9: Conn_01x04; PinHeader_1x01_P2.54mm_Vertical
R1, R36, R41: 47k; R_Axial_DIN0207_L6.3mm_D2.5mm_P7.62mm_Horizontal
R2, R27: 4,7k; R_Axial_DIN0207_L6.3mm_D2.5mm_P7.62mm_Horizontal
R3, R5, R10, R11, R16, R23, R24, R39: 5,6k; R_Axial_DIN0207_L6.3mm_D2.5mm_P7.62mm_Horizontal
R4, R12, R13, R25, R26, R30, R32, R34: 1k; R_Axial_DIN0207_L6.3mm_D2.5mm_P7.62mm_Horizontal
R8, R9, R14: 2,7k; R_Axial_DIN0207_L6.3mm_D2.5mm_P7.62mm_Horizontal
R15, R17, R28: 330; R_Axial_DIN0207_L6.3mm_D2.5mm_P7.62mm_Horizontal
R31: 6,8k; R_Axial_DIN0207_L6.3mm_D2.5mm_P7.62mm_Horizontal
R33: 150; R_Axial_DIN0207_L6.3mm_D2.5mm_P7.62mm_Horizontal
R35: 10k; R_Axial_DIN0207_L6.3mm_D2.5mm_P7.62mm_Horizontal
R37: 0; R_Axial_DIN0207_L6.3mm_D2.5mm_P7.62mm_Horizontal
R38: 1,2k; R_Axial_DIN0207_L6.3mm_D2.5mm_P7.62mm_Horizontal
R40: 220; R_Axial_DIN0207_L6.3mm_D2.5mm_P7.62mm_Horizontal
U1: L7805; TO-220-3_Vertical
U2: ACPL-844; DIP-16_W7.62mm_LongPads
U4: 7824; TO-220-3_Vertical

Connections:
24V: C15.1, D12.2 (A), R14.2, U4.3 (OUT); also elsewhere on the board
+5V: C4.1, C7.1, C8.1, D13.2 (A), J7.3, J8.4, J11.1, R3.1, R5.2, R10.1, R11.1, R16.2, R17.2, R23.2, R24.1, R37.2, R39.2, U1.3 (OUT)
/0: D2.2 (~~), D4.2 (A2), D10.2 (A2), J3.5, J4.2, J4.3, J4.5
/1: J4.4
/3P: J4.6
/7: J4.7, R27.1
/10: D4.1 (A1), F4.1, J4.1, R40.1
/12: J3.6
/24: F2.1, F4.2, J3.7
/24VR: D2.1 (+), D3.2 (A), D5.2 (A)
/+: J10.1, R37.1
/Bp+: A1.14 (D11), Bp+1.1, Bp+1.2, R16.1
/Bp-: A1.15 (D12), Bp-1.1, Bp-1.2, R23.1
/BpEch: A1.11 (D8), BpEch1.1, BpEch1.2, R39.1
/BpEnt: A1.12 (D9), Bp-Ent1.1, Bp-Ent1.2, R5.1
/CX: J4.8, R2.1
/CY: J4.9
/D: J10.3, R34.2
/DATA: A1.5 (D2), R38.2, R41.2
/E: J10.2, R33.1
/ERR: J8.3
/Encod: R26.2, R34.1, R35.2
/F: C20.1, J5.3, R14.1
/FA: C19.1, J5.2, R9.2
/FC: C1.1, J5.1, R8.2
/Onde: A1.25 (A6), C10.1, D14.1 (K), R30.1
/SCL: A1.24 (A5), R28.2
/SDA: A1.23 (A4), R15.2
CT: J3.3; also elsewhere on the board
GND: A1.4 (GND), A1.29 (GND), Bp+1.3 (K), Bp+1.4 (A), Bp-1.3 (K), Bp-1.4 (A), Bp-Ent1.3 (K), Bp-Ent1.4 (A), BpEch1.3 (K), BpEch1.4 (A), C1.2, C2.2, C4.2, C7.2, C8.2, C9.2, C10.2, C15.2, C16.2, C19.2, C20.2, D2.3 (-), D9.1 (K), D14.2 (A), J6.1, J7.4, J8.1, J11.2, J11.3, R32.1, R33.2, R35.1, R41.1, U1.2 (GND), U2.4, U2.6, U2.9, U2.11, U2.13, U2.15, U4.2 (GND); also elsewhere on the board
N: C18.2, FL1.4, J3.2; also elsewhere on the board
unnamed: A1.6 (D3), R26.1
unnamed: A1.7 (D4), R4.1
unnamed: A1.8 (D5), R12.1
unnamed: A1.9 (D6), R13.1
unnamed: A1.10 (D7), R25.1
unnamed: A1.27 (+5V), D13.1 (K)
unnamed: C5.1, D1.2 (A2), F1.2, FL1.1
unnamed: C5.2, D1.1 (A1), FL1.3, J1.2
unnamed: C9.1, D12.1 (K), U1.1 (IN)
unnamed: C2.1, C16.1, D3.1 (K), U4.1 (IN)
unnamed: D5.1 (K), R31.2
unnamed: D9.2 (A), R17.1
unnamed: D2.4 (~~), D10.1 (A1), F2.2
unnamed: F1.1, J1.1
unnamed: J7.1, R15.1
unnamed: J7.2, R28.1
unnamed: J8.2, R38.1
unnamed: J6.2, J9.1, J11.4
unnamed: R1.1, R36.1, R40.2, U2.1, U2.7
unnamed: R1.2, R2.2, U2.2
unnamed: R3.2, R4.2, U2.16
unnamed: R8.1, U2.3
unnamed: R9.1, U2.5
unnamed: R10.2, R12.2, U2.14
unnamed: R11.2, R13.2, U2.12
unnamed: R24.2, R25.2, U2.10
unnamed: R27.2, R36.2, U2.8
unnamed: R30.2, R31.1, R32.2
Ph: C18.1, FL1.2, J3.1; also elsewhere on the board
R2: A1.20 (A1); also elsewhere on the board
R3: A1.21 (A2); also elsewhere on the board
R4: A1.22 (A3); also elsewhere on the board
Var: A1.13 (D10); also elsewhere on the board

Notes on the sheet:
entrée 220V
Transfo
Commande
ouv/ferm
Fins de course
Antenne
Ouvert
Fermé
Récepteur télécommande 433 MHz
led intégrée
TDCA RX500A CHJ-9921 RXB6
Ecran OLED
Boutons poussoir
Alimentation 5V arduino
Alimentation 24V relais
Encodeur
Cellule
la manoeuvre du portail est réalisée par un BP connecté 5 et 7 (mise au 0V de 7)
Phase
Neutre
Phase réduite 220V
PWM
32V PkPk
4,7V PkPk
1=arrêt mvt 3P=ouverture partielle
Numérisation de la sinusoïde du secteur
24V Ac
24Vac
24Vcc
24Vac 34VPkPk
1A-F
5A-F
connecteurs femelle
connecteur femelle
fermé
ouvert
ANT
32V PkPk
ACPL-844 ou 4xSFH620

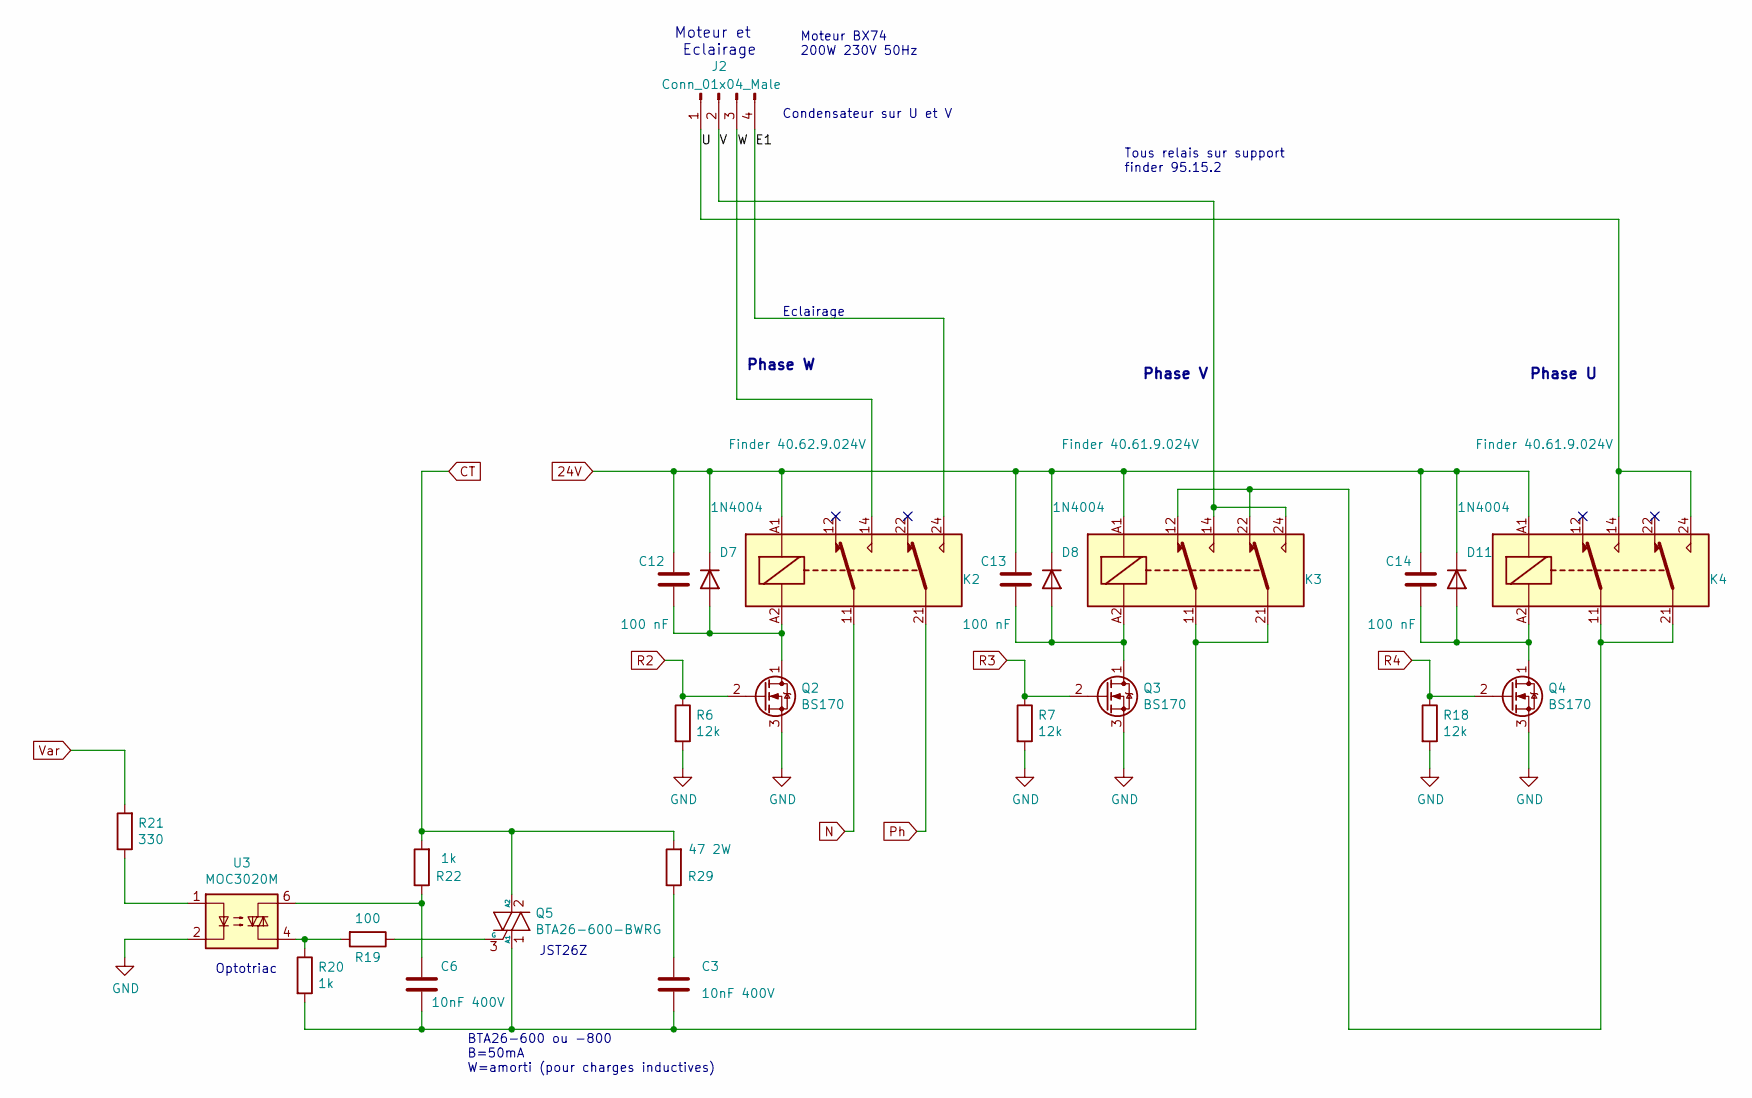
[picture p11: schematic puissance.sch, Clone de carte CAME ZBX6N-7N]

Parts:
C3, C6: 10nF 400V; C_Rect_L9.0mm_W2.5mm_P7.50mm_MKT
C12, C13, C14: 100 nF; C_Rect_L7.2mm_W2.5mm_P5.00mm_FKS2_FKP2_MKS2_MKP2
D7, D8, D11: 1N4004; D_DO-41_SOD81_P10.16mm_Horizontal
J2: Conn_01x04_Male; PhoenixContact_MSTBVA_2,5_4-G-5,08_1x04_P5.08mm_Vertical
K2: Finder 40.62.9.024V; Relay_socket_95.15.2
K3, K4: Finder 40.61.9.024V; Relay_socket_95.15.2
Q2, Q3, Q4: BS170; TO-92L_Inline_Wide
Q5: BTA26-600-BWRG; TO-3P-3_Vertical
R6, R7, R18: 12k; R_Axial_DIN0207_L6.3mm_D2.5mm_P7.62mm_Horizontal
R19: 100; R_Axial_DIN0207_L6.3mm_D2.5mm_P7.62mm_Horizontal
R20, R22: 1k; R_Axial_DIN0207_L6.3mm_D2.5mm_P7.62mm_Horizontal
R21: 330; R_Axial_DIN0207_L6.3mm_D2.5mm_P7.62mm_Horizontal
R29: 47 2W; R_Axial_DIN0414_L11.9mm_D4.5mm_P15.24mm_Horizontal
U3: MOC3020M; DIP-6_W7.62mm_LongPads

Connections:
24V: C12.1, C13.1, C14.1, D7.1 (K), D8.1 (K), D11.1 (K), K2.A1, K3.A1, K4.A1; also elsewhere on the board
/puissance/E1: J2.4, K2.24
/puissance/U: J2.1, K4.14, K4.24
/puissance/V: J2.2, K3.14, K3.24
/puissance/W: J2.3, K2.14
CT: Q5.2 (A2), R22.2, R29.2; also elsewhere on the board
GND: Q2.3 (S), Q3.3 (S), Q4.3 (S), R6.2, R7.2, R18.2, U3.2; also elsewhere on the board
N: K2.11; also elsewhere on the board
unnamed: C3.1, R29.1
unnamed: C3.2, C6.2, K3.11, K3.21, Q5.1 (A1), R20.2
unnamed: C6.1, R22.1, U3.6
unnamed: C12.2, D7.2 (A), K2.A2, Q2.1 (D)
unnamed: C13.2, D8.2 (A), K3.A2, Q3.1 (D)
unnamed: C14.2, D11.2 (A), K4.A2, Q4.1 (D)
unnamed: K3.12, K3.22, K4.11, K4.21
unnamed: Q5.3 (G), R19.1
unnamed: R19.2, R20.1, U3.4
unnamed: R21.1, U3.1
Ph: K2.21; also elsewhere on the board
R2: Q2.2 (G), R6.1; also elsewhere on the board
R3: Q3.2 (G), R7.1; also elsewhere on the board
R4: Q4.2 (G), R18.1; also elsewhere on the board
Var: R21.2; also elsewhere on the board

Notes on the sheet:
Tous relais sur support finder 95.15.2
Moteur et Eclairage
Optotriac
Phase V
Phase U
Phase W
Eclairage
Condensateur sur U et V
JST26Z
Moteur BX74 200W 230V 50Hz
BTA26-600 ou -800 B=50mA W=amorti (pour charges inductives)

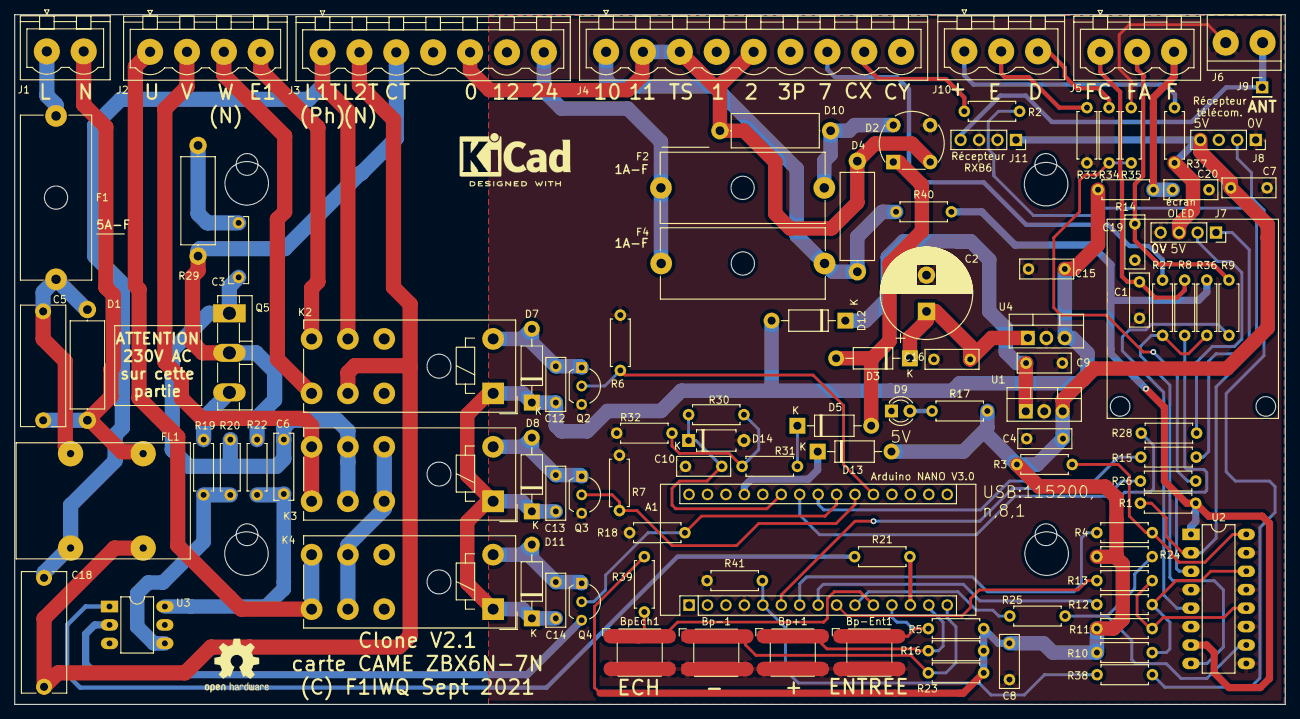
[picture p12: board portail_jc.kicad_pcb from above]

Board: 2 copper layers, 175.0 x 95.0 mm, 115 parts (0 on the bottom side), 73 nets.

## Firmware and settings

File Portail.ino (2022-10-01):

// portail IWQ carte CAME ZBX6N/7N - Version 30 09 2022 18h
// moteur asynchrone
// pour ARDUINO NANO - F1IWQ
// si clone de NANO : choisir processeur : ATMEGA 328P Old bootloader
// si vrai NANO     : choisir processeur : ATMEGA 328P
// pour la compilation et le téléchargement, sélectionner arduino NANO sinon le téléchargement ne fonctionnera pas.
// Ne pas utiliser Tempo() dans la fonction traitement() ni dans les fonctions à l'intérieur à savoir recul_lent() et avance_lent() mais delay.
// L'origine 0 de l'encodeur est en position reculée (Fc arrière)=portail ouvert
// *********************************************************
// Compilation pour la carte V1.0 ou V2.0
// en V1 : l'encodeur est traité par l'IRQ matérielle, encod sur pin D8.
// ----------------------------------------------------------------------------------
// en V2 : l'encodeur est traité par l'IRQ matérielle, encod sur pin D3
// ----------------------------------------------------------------------------------
// 1 tour programme principal (main) dure en moyenne 800 à 850µs
//
#define V1   // carte V1.0 ou V2.0
//#define modes_etendus  // modes de pilotage supplémentaires du moteur. Uniquement pour test

#include <TimerOne.h>
#include <EEPROM.h>
// récepteur 433
#include <RCSwitch.h>

// bibliothèque ssd1306ascii allégée pour nano pour écran oled
#include <SSD1306Ascii.h>
#include <SSD1306AsciiAvrI2c.h>
#include <SSD1306AsciiSoftSpi.h>
#include <SSD1306AsciiSpi.h>
#include <SSD1306AsciiWire.h>
#include <SSD1306init.h>

// écran oled
#define I2C_ADDRESS 0x3C   
// Sans broche RESET
#define RST_PIN -1

// organisation des lignes de l'écran d'exploitation---------------------
#define ligne_encodeur   3
#define ligne_erreur     7

#define Tempo_sortie_menu 20 // 20 s
// organisation des Y lignes de l'écran MENU (1)
#define premiere_ligneM  1
#define derniere_ligneM  9
#define offset_M         2  // début de l'affichage en Y=2

#define ligne_aprentiss  1  // lancement de l'apprentissage
#define ligne_Param_sens 2  // paramètre F54 : sens d'ouverture du portail
#define ligne_Param_PPS  3  // paramètre F7  : 0=ouverture complète/fermeture complète  1=ouverture/arret/fermeture/arret
#define ligne_eprom      4  // Sauvegarde des paramètres en EPROM
#define ligne_telecom    5  // Gestion des télécommandes
#define ligne_ES         6  // affichage des E/S
#define ligne_tpsmax     7  // temps maxi de fonctionnement
#define ligne_acc        8  // 
#define ligne_dec        9  // 


const String ligne_menu_S[]={"Apprentissage",
                             "Sens d'ouverture=",
                             "Sequencement=",
                             "Sauvegarde EPROM",
                             "Gestion telecommandes",
                             "Affichage entrees",
                             "Tps max fonction=",
                             "Tps accel=",
                             "Tps decel="};

// organisation des lignes de l'écran télécommandes (2)
#define premiere_ligneT  1
#define derniere_ligneT  2
#define Offset_T         3  // début en Y=3

#define ligne_telecomA   1  // Ajouter une télécommande
#define ligne_telecomL   2  // Liste et suppression des télécommandes

// ports d'entrées / sorties----------------------------------------
#define   led       13     // D13 portB.5 led intégrée
#define   BpM       12     // D12 portB.4 Bouton -
#define   BpP       11     // D11 portB.3 Bouton +
#define   Var       10     // D10 portB.2 Variation (commande triac)
#define   BpE        9     // D9  portB.1 Bouton ENTREE
#define   Commande   7     // D7  portD.7 ommande ouverture/fermeture 
#define   FcFerme    6     // D6  portD.6 Fin de course fermé
#define   FcOuvert   5     // D5  portD.5 Fin de course ouvert
#define   Cellule    4     // D4  portD.4 Photo-cellule
#define   data       2     // D2  portD.2 Rx radio 433 MHz

#ifdef    V1               // définitions spécifiques de la carte V1
#define   encod      8     // D8  portB.0 Encodeur 
#define   BpEch      3     // D3  portD.3 Bouton Ech
#endif

#ifdef    V2               // définitions spécifiques de la carte V2
#define   encod      3     // D3  portD.3 Encodeur 
#define   BpEch      8     // D8  portB.0 Bouton Ech
#endif

// port C de l'ATMEGA328 
#define   Scl       A5     // portC.5 SCL
#define   Sda       A4     // portC.4 SDA
#define   R4        A3     // portC.3 bit 3 Relais 4
#define   R3        A2     // portC.2 bit 2 Relais 3
#define   R2        A1     // portC.1 bit 1 Relais 2
#define   Tick      A0     // portC.0 bit 0 tour programme debug oscilloscope
// A6 et A7 uniquement en entrée analogiques - 10 bits valeurs de 0 à 1023.
#define   Onde      6     // A6 numérisation signal secteur 
#define   rien      7     // A7

#define   Nbre_Max_telecom 20  // nombre maxi de télécommandes 

volatile int  erreur,ech,valeur,compsec,Compt10Sec,secondes,nombre,i,compteur_ech,val_secteur[50];
volatile int  Temps_boutonM,Temps_boutonP,val_tempo,ligne_menu,PosRalenti_ferm,PosRalenti_ouv ;
volatile int  Nbre_demi_sinus,angle_retard,Temps_boutonE,AncErreur,Aech,Seq,Temps_boutonEch;
volatile int  Tempo_menu,derniere_ligne,premiere_ligne,PageMenu,cpt_mvt,Seq_mvt,attendre,timer;
volatile int  Nbre_telecom,tempo_affT,Nbit,Protocole,Temps_bornier,Tps_fonctionnement,Tps_fonc_P;
volatile int  decale,offset,Tps_cellule,Tps_ctrl_encod,cpt_mvt_10,AAAech,AAech,mem_delta,delta;
volatile int  PosEncodeur,Anc_Encodeur,vitesse,AncPos,Tps_accP,Tps_acc,Tps_dec,Tps_decP;
volatile byte Sens_Ouv,Sens_Ouv_P,PPS,PPS_P,octet,compt_vit,TpsRalenti_ouv,TpsRalenti_ferm;
volatile bool demande_arret,posOnde,trouveOnde,etatencod,ancetatencod,Fc_ferme,Fc_ouvert,avance,recul ; 
volatile bool Aferme,Aouvert,simu,recul_cours,avance_cours,posOk,MemRecul,MemAvance,memo_lent ;
volatile bool dem_inc_boutonM,dem_inc_boutonP,Cellule_ok,ACellule,menu,Anc_BpP,Anc_BpM,Anc_BpE ;
volatile bool simuMenu,Simu8,Simu2,Enter,m1,m2,m3,m4,m23,Anc_BpEch,Etat_BpP,Etat_BpM,Msg_cell_ok;
volatile bool dem_inc_boutonE,md2,md3,mode_test,Etat_BpE,Etat_BpEch,dem_cpt_mvt,curseur;
volatile bool Fm_M,Fm_E,Fm_P,Fm_Ech,Aff_ES,dem_inc_boutonEch,Fm_O,Fm_F,Fd_O,Fd_F,Dem_Telecom;
volatile bool Dem_Liste_Tel,radio,arrete,Cde_bornier,Fm_Bornier,Abornier,demande_arr_imm;
volatile bool demande_recul_imm,FmBornier,Man_Bornier,Err_enc,m34,mode_temps;
volatile bool Msg_cell_nok,Verrou,Fm_Verrou,AVerrou,Fd_Verrou,msgVerr;
volatile long iteration,Code,telecom[Nbre_Max_telecom];
char          inByte ;
String        s,chaine,vide,chaineEnCours ;

SSD1306AsciiWire oled;
RCSwitch Rx = RCSwitch();

// Interruption matérielle de l'encodeur appellée si changement de front sur 
// l'entrée D8: D8 à D13 en V1
// l'entrée D3 en V2
#ifdef V1
ISR (PCINT0_vect)
#endif
#ifdef V2
void gest_encodeur()
#endif
{
  // Serial.println(digitalRead(encod));
  // intégration encodeur, pris en compte uniquement sur un mouvement moteur ---------
  if (avance_cours | recul_cours) 
  {
    if (avance_cours) ++PosEncodeur;  // avance
    if (recul_cours)  --PosEncodeur;  // recul
  } 
}

// 4608 / $1200 = 1 génère seconde
// 1 interruption timer toutes les 217,01388 micro secondes (0.217 ms) (4608 Hz)
// le signal 100 Hz a une période de 10 ms, soit 10/0,217 = 46 passages dans l'interruption.
void Interrupt_T1() 
{
  // lecture tension secteur
  if (bit_is_clear(ADCSRA,ADSC))  // échantillon prêt ?
  {  
    ++compteur_ech;  // nombre d'échantillons depuis le dernier passage à 0
    AAAech=AAech;
    AAech=Aech;
    Aech=ech;        // ancienne valeur
    ech=ADC;         // lire la valeur analogique de la phase secteur

    // demande de conversion analogique suivante
    ADMUX=(0xf0 & ADMUX) | Onde ;    // A6 au multiplexeur 
    ADCSRA |=(1 << ADSC);            // mise à 1 du bit ADSC du registre ADCSRA (demande de conversion)   
    
    // stocker dans tableau la phase (uniquement pour inspection manuelle)
    if ((compteur_ech<50) & (compteur_ech>=0) & (erreur!=1)) val_secteur[compteur_ech]=ech;
    
    // détection min sinusoide 
    posOnde=(AAAech>AAech) & (Aech<ech) & (ech<250); 
    if (posOnde & !trouveOnde)
    {
      trouveOnde=HIGH;
      if (erreur==1) erreur=0; 
      ++Nbre_demi_sinus;
      compteur_ech=0;
      if (erreur!=1) val_secteur[compteur_ech]=ech;

      // conditions de RAZ du compteur de nombre de demi sinusoïdes en fonction du mode
      if ( (m2  & (Nbre_demi_sinus>=4)) |   // pour les modes m: toujours RAZ sur un nombre pair car on envoie une sinusoïde complète 1x tous les n
           (m3  & (Nbre_demi_sinus>=6)) |
           (m4  & (Nbre_demi_sinus>=8)) |
           (md2 & (Nbre_demi_sinus>=3)) |   // pour les modes md: toujours RAZ sur un nombre impair car on envoie une demi sinusoïde m sur n
           (md3 & (Nbre_demi_sinus>=5)) |
           (m23 & (Nbre_demi_sinus>=6)) |
           (m34 & (Nbre_demi_sinus>=8)) 
         ) 
      Nbre_demi_sinus=0;       
    }

    if (!posOnde) trouveOnde=LOW;

    // erreur si on a pas détecté la phase 0 au bout de 60 échantillons
    if (compteur_ech>60)
    {
      erreur=1; 
      //Serial.println("E");
      compteur_ech=0;
    }
  
    // pilotage de la pin VAR à 1 si pas arrêté
    if ( !arrete & (compteur_ech>=angle_retard) & (compteur_ech<angle_retard+10) & // +10 détermine la largeur du créneau envoyé à la gachette
         ( 
            m1 | 
           (m2 & (Nbre_demi_sinus<2)) | 
           (m3 & (Nbre_demi_sinus<2)) |  
           (m4 & (Nbre_demi_sinus<2)) | 
          (md2 & (Nbre_demi_sinus<1)) | 
          (md3 & (Nbre_demi_sinus<1)) | 
          (m23 & (Nbre_demi_sinus<4)) |
          (m34 & (Nbre_demi_sinus<6))
         )
       )
    {
     digitalWrite(Var,1);
     digitalWrite(led,1);
    }    
    // si on dépasse la consigne, on ne pilote pas la sortie gachette "var"
    else 
    {
      digitalWrite(Var,0);  
      digitalWrite(led,0);
    }
  }

  ++compsec;       // compteur 1 seconde
  ++Compt10Sec;    // compteur 1/10eme de seconde

  // compteurs appui boutons (en temps timer 217µs)
  if (dem_inc_boutonM) ++Temps_boutonM;
  if (dem_inc_boutonP) ++Temps_boutonP;
  if (dem_inc_boutonE) ++Temps_boutonE;
  if (dem_inc_boutonEch) ++Temps_boutonEch;

  // séquenceur 1/10 seconde---------------
  if (Compt10Sec>=460)
  {
    Compt10Sec=0;

    if (dem_cpt_mvt) ++cpt_mvt_10; else cpt_mvt_10=0;  // compteur mvt en 1/10 de s
    // vérification de l'encodeur----------------------
    if (!mode_test & !mode_temps)  // si mode_test=1 ou mode_temps=1, on ne vérifie pas l'encodeur
    {
      if ( (avance_cours | recul_cours) & (cpt_mvt_10>10) ) // contrôle de l'encodeur après 1,0s de mouvement (pour l'accélération)
      {
        --Tps_ctrl_encod;
        if (Tps_ctrl_encod<=0) 
        {
          Tps_ctrl_encod=5;     // vérification toutes les 0,5 seconde
          delta=PosEncodeur-Anc_Encodeur;   
          if (
               ((abs(delta)<80) & !memo_lent) | // 80=nombre de points codeurs, augmenter la valeur pour augmenter le seuil de détection d'erreur
               ((abs(delta)<20) & memo_lent)  // 100=nombre de points codeurs, augmenter la valeur pour augmenter le seuil
             )  
          { 
            // erreur pas de changement de l'encodeur pendant un mouvement: peut être obstacle!
            if (memo_lent) erreur=3; else erreur=4;
            Err_enc=HIGH;
            mem_delta=delta;
            if (avance_cours) demande_recul_imm=HIGH; // sur une avance, on recule sans décélération
            else demande_arr_imm=HIGH;                // sur un recul, on arrete sans décélération
          }   
          else 
          {
            Err_enc=LOW;
            if ((erreur==3) | (erreur==4)) {erreur=0;}  
          }
        Anc_Encodeur=PosEncodeur;
        }
      }     
    }  
    
    // vitesse du portail: mesure toutes les 0,3 s
    ++compt_vit;
    if (compt_vit>=3)
    {
      compt_vit=0;     
      vitesse=AncPos-PosEncodeur;
      AncPos=PosEncodeur;
    }  
    
    if (val_tempo!=0) --val_tempo;
  }
  // seconde
  if (compsec>=4608)
  {
    compsec=0;
    ++secondes;
    if (tempo_affT!=0) --tempo_affT;
    if (dem_cpt_mvt) ++cpt_mvt;
    if (Tempo_menu>0) ++Tempo_menu;
  }  

  // les signaux cellule et commande présentent un pic de tension haut toutes les 10ms
  // car ils sont alimentés par un optocoupleur AC (U2A et U2D)
  // filtrage à 60x0,217ms = 13 ms : tempo de recouvrement suffisante
  // filtrage cellule 
  ACellule=Cellule_ok;
  if ((digitalRead(Cellule))==LOW) {Tps_cellule=60;Cellule_ok=HIGH;}
  if (Tps_cellule>0) 
  {
    --Tps_cellule;
    if (Tps_cellule==0) Cellule_ok=LOW;
  }
  if (!ACellule & Cellule_ok) Msg_cell_ok=HIGH;
  if (ACellule & !Cellule_ok) Msg_cell_nok=HIGH;

  // filtrage commande
  Abornier=Cde_bornier;
  if ((digitalRead(Commande))==LOW) {Temps_bornier=60;Cde_bornier=HIGH;}
  if (Temps_bornier>0) 
  {
    --Temps_bornier;
    if (Temps_bornier==0) {Cde_bornier=LOW;}
  }
  Fm_Bornier=!Abornier & Cde_bornier;
  if (Fm_Bornier) Man_Bornier=!menu;
} 

// masque de l'écran de base
void Ecran_base()
{
  oled.setInvertMode(0);
  oled.setFont(System5x7);
  oled.clear();
  oled.set2X();
  oled.println(F("Portail JC")); 
  oled.set1X();
  //oled.setScrollMode(SCROLL_MODE_AUTO);
  oled.setScrollMode(SCROLL_MODE_OFF);
  oled.setCursor(0,ligne_encodeur);oled.println(F("Pos=0"));
}
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
void loop() 
{
  //digitalWrite(Tick,HIGH);
  ++iteration;
  if (iteration>32000) iteration=0;
      
  traitement();    // traitement de fond
  //digitalWrite(Tick,LOW);
  
  if (!menu)
  { 
    // affichage erreur
    if ((AncErreur==0) & (erreur==1))
    { 
      AncErreur=erreur;
      s=F("Secteur non trouve  ");
      Serial.println(s);
      oled.setCursor(0,ligne_erreur);oled.print(s);
    }

    if ((AncErreur==1) & (erreur==0))
    { 
      AncErreur=erreur;
      s=F("Secteur trouve     ");
      Serial.println(s);
      oled.setCursor(0,ligne_erreur);oled.print(s);
    }

    if ((AncErreur==0) & (erreur==2))
    { 
      AncErreur=erreur;
      s=F("Erreur mvt trop long");
      oled.setCursor(0,ligne_erreur);oled.print(s);
      Serial.println(s);
    }  

    if ((AncErreur!=0) & (erreur==0))
    { 
      AncErreur=erreur;
      oled.setCursor(0,ligne_erreur);oled.print(vide);
    }
    
    if ((AncErreur==0) & ((erreur==3) | (erreur==4)))
    { 
      AncErreur=erreur;
      s=F("Encodeur muet ");
      if (erreur==3) s=s+F(("en lent  ")); else s=s+F(("en rapide "));
      oled.setCursor(0,ligne_erreur);oled.print(s);
      Serial.print(s);Serial.println(mem_delta);
    }  

    // Affichage Evt Fdc et cellule ----------------------------------------------------------
    if (Fm_F)
    {
      s=F("Fdc ferme ");
      Serial.println(s);
      oled.setCursor(0,4);oled.println(s);
    }
    if (Fd_F)
    {
      Serial.println(F("Fdc ferme libéré"));
      oled.setCursor(0,4);oled.println(vide);
    }
    
    if (Fm_O)
    {
      s=F("Fdc ouvert");
      Serial.println(s);
      oled.setCursor(0,4);oled.println(s);
    }
    if (Fd_O)
    {
      Serial.println(F("Fdc ouvert libéré"));
      oled.setCursor(0,4);oled.println(vide);
    }

    if (Msg_cell_ok)
    {
      Msg_cell_ok=LOW;
      s=F("Cellule OK    ");
      Serial.println(s);
      oled.setCursor(0,6);oled.println(s);
    } 

    if (Msg_cell_nok)
    {
      Msg_cell_nok=LOW;
      s=F("Cellule coupee");
      Serial.println(s);
      oled.setCursor(0,6);oled.println(s);
    }

    if (Fd_Verrou)
    {
      Serial.println(F("Portail déverrouillé"));
      oled.setCursor(0,4);oled.println(vide);
    }

    if (Fm_Verrou | msgVerr)
    {
      s=F("Portail verrouille ");
      msgVerr=LOW;
      Serial.println(s);
      oled.setInvertMode(1);
      oled.setCursor(0,4);oled.println(s);
      oled.setInvertMode(0);
    }   
  }
    
  //réception des données depuis USB
  nombre=Serial.available() ; // nombre de caractères disponibles sur la liaison série
  if (nombre>0)
  {
    //Serial.println(nombre);
    for (i=0 ; i<nombre ; i++)
    {
      inByte = Serial.read();
      //Serial.print(inByte);
      //if (inByte==13) Serial.print("CR");
      //if (inByte==10) Serial.print("LF");
      if ((inByte!=13) & (inByte!=10)) chaineEnCours=chaineEnCours+inByte;
      if (inByte==13)
      {  
        //Serial.println("CR");Serial.println(chaineEnCours);
        if (menu) Tempo_menu=1;
        chaine=chaineEnCours;
        if (chaine=="") {demande_arret=!menu;Enter=HIGH;}  // pas de demande d'arret en mode menu
        //Serial.println();
        //Serial.print("chaine=");Serial.println(chaine);
        chaineEnCours=""; 
      }
    }
  }    

  if (chaine=="?") 
  {
    Serial.println(F("angle xx: Angle retard"));  
    Serial.println(F("m1 à m6 : 1 sinusoide sur 1..6"));
    Serial.println(F("md2 à 6 : 1/2 sinusoide sur 2..5"));
    tempo(1);
    Serial.println(F("sec     : Affiche la sinusoide du secteur\r\npos     : Affiche la position de l'encodeur")); 
    Serial.println(F("tar     : Avance en rapide")); 
    tempo(1);
    Serial.println(F("trr     : Recul en rapide\r\ntal     : Avance en lent\r\ntrl     : Recul en lent")); 
    tempo(1);  
    Serial.println(F("ENTREE  : Arret")); 
    Serial.println(F("e       : Etat des entrees"));   
    tempo(1);  
    Serial.println(F("simu    : Simu commande bornier"));
    Serial.println(F("menu    : Mode menu (touches 8/2 = < >)"));
    Serial.println(F("im      : Infos menu"));
    chaine="";
  }
  else

  if (chaine.substring(0,5)==F("angle"))
  {
    chaine.remove(0,5); // reste la valeur
    angle_retard=chaine.toInt();
    if ((angle_retard<0) | (angle_retard>70)) Serial.println(F("Erreur valeur angle"));
    else {Serial.print(F("Angle fixe a "));Serial.println(angle_retard);}
    chaine="";
  }
  else

  if (chaine==F("m1"))
  {
    Serial.println(F("mode 1"));
    mode1();
    chaine="";
  }
  else

  if (chaine==F("m2"))
  {
    Serial.println(F("mode 2"));
    mode2();
    chaine="";
  }
  else

  #ifdef modes_etendus
  if (chaine==F("m23"))
  {
    Serial.println(F("mode 23"));
    mode_23();
    chaine="";
  }
  else

  if (chaine==F("m34"))
  {
    Serial.println(F("mode 34"));
    mode_34();
    chaine="";
  }
  else
  
  if (chaine==F("m3"))
  {
    Serial.println(F("mode 3"));
    mode3();
    chaine="";
  }
  else

  if (chaine==F("md2"))
  {
    Serial.println(F("mode D2"));
    moded2();
    chaine="";
  }
  else

  if (chaine==F("md3"))
  {
    Serial.println(F("mode D3"));
    moded3();
    chaine="";
  }
  else
  #endif

  if (chaine==F("menu"))
  {
    simuMenu=HIGH;
    Serial.println(F("Mode MENU"));
    chaine="";
  }
  else

  if (chaine==F("8"))
  {
    Simu8=HIGH;
    chaine="";
  }
  else

  if (chaine==F("2"))
  {
    Simu2=HIGH;
    chaine="";
  }
  else
  
  if (chaine==F("simu"))
  {
    simu=HIGH;
    chaine="";
  }
  else

  if (chaine.substring(0,3)=="e")
  {
    Serial.print(F("Encodeur   ")); Serial.println(digitalRead(encod));
    Serial.print(F("Fc Ferme   ")); Serial.println(digitalRead(FcFerme));
    Serial.print(F("Fc Ouvert  ")); Serial.println(digitalRead(FcOuvert));
    tempo(1);
    Serial.print(F("Cellule    ")); Serial.println(digitalRead(Cellule));
    Serial.print(F("Commande   ")); Serial.println(digitalRead(Commande));
    Serial.print(F("Bouton ECH ")); Serial.println(digitalRead(BpEch));
    tempo(1);
    Serial.print(F("Bouton E   ")); Serial.println(digitalRead(BpE));
    Serial.print(F("Bouton +   ")); Serial.println(digitalRead(BpP));
    Serial.print(F("Bouton -   ")); Serial.println(digitalRead(BpM));
    
    chaine="";
  }
  else
  
  if (chaine==F("sec"))
  {
    Serial.print(F("Erreur="));Serial.println(erreur);
    for (i=0 ; i<=50 ; i++)
    {
      Serial.print(i);Serial.print(F(" "));
      Serial.println(val_secteur[i]);
    }
    chaine="";
  }
  else 

  if (chaine==F("pos"))
  {
    Serial.print(F("Position encodeur="));Serial.println(PosEncodeur);
    chaine="";
  }  
  else
   
  // avance rapide
  if (chaine==F("tar"))
  {  
    avance_rapide();
    chaine="";
  }
  else

  // recul rapide
  if (chaine==F("trr"))
  {
    recul_rapide();
    chaine="";
  }
  else

  // avance lente
  if (chaine==F("tal"))
  {
    avance_lente();
    chaine="";
  }
  else

  // recul lent
  if (chaine==F("trl"))
  {
    recul_lent();
    chaine="";
  }
  else
  
  if (chaine==F("im"))
  {
    Serial.print(F("Menu="));Serial.println(menu);
    Serial.print(F("ligne menu="));Serial.println(ligne_menu);
    Serial.print(F("Page="));Serial.println(PageMenu);
    Serial.print(F("Curseur="));Serial.println(curseur); 
    chaine="";
  }

  else
  if (chaine!="")
  {
   Serial.print(F("Commande inconnue:"));Serial.println(chaine);
   chaine="";
  }

  // demande de mouvement depuis le bornier (J4 bornes 2/7) ou radio -----------------------
  if (((Man_Bornier | radio) & !menu) | simu)  
  {  
    if (Man_Bornier) s=F("Commande bornier");
    if (radio) s=F("Commande radio  ");
    Man_Bornier=LOW;
    radio=LOW;   
    simu=LOW;
    Serial.println(s);
    oled.setCursor(0,5);oled.println(s);

    // si arreté sur un FdC 
    if (Fc_ouvert | Fc_ferme)
    {
      Serial.println(F("cas1"));
      if (!avance_cours & !recul_cours) 
      {
        if (Fc_ouvert) avance_rapide();
        if (Fc_ferme)  recul_rapide();
      }  
    }  
    
    else
    {
      // si pas arrété sur un FdC et pas de mvt en cours
      if (!avance_cours & !recul_cours)
      {
        Serial.println(F("cas2"));
        // dernier mvt était recul ou avance?
        if (recul) avance_rapide(); else recul_rapide(); 
      }
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
